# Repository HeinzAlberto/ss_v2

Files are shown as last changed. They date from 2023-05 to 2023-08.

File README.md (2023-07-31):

# ss_v2
Soldering Station v2 Projekt

Das Soldering Station v2 Projekt basiert auf dem SolderingStation Projekt: https://github.com/ConnyCola/SolderingStation.
Da dieses Projekt nun schon einige Jahre alt ist und mir ein paar kleine Tweeks wie USB-C input oder User-Buttons fehlen, ist dies somit die inoffizielle Fortsetzung.
Der Code basiert maßgebend auf dem des Originalprojekts. 
Hinzugefügt wurde:
- User-Buttons Funktionen (speichern, abrufen und löschen von selbst festgelegten Temperaturwerten)
- Automatisches Standby, wenn PWM über gewisse Zeit einen Wert nicht überschreitet
- Menü, um obriges einzustellen

Die Schaltung basiert ebenfalls auf dem Originalprojekt, wobei hier einige Änderungen vorgenommen wurden:
- Der uC (Atmega328p) wird direkt integriert.
- Es werden drei programmierbare Nutzer-Buttons hinzufügt, z.B. für voreingestellte Temperaturen oder Standby.
- Über einen Pin kann mit einem Federkontakt der Lötkolben automatisch in den Standy gesetzt werden, wenn er in die Halterung gelegt wird.
- Es gibt nun eine AVR-ISP-Schnittstelle zur Programmierung.
- Der OpAmp wurde durch ein günstigeres Modell ersetzt.
- Es gibt neben dem bisherigen Rundstecker auch einen USB-C Anschluss, der Power Delivery (USB-PD) unterstützt.
- Ein Kippschalter wird eingesetzt, um zwischen Rundstecker und USB-C zu schalten um somit reverse-current zu verhindern.

ToDo:
Der gesamte Programmierteil sowie ein Prüfen der Schaltung.

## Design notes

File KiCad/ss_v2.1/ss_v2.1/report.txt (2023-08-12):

Hinweis: Verarbeite Symbol "Q1:Package_TO_SOT_SMD:SOT-23".
Hinweis: Verarbeite Symbol "R21:Resistor_SMD:R_1206_3216Metric_Pad1.30x1.75mm_HandSolder".
Hinweis: Verarbeite Symbol "R3:Resistor_SMD:R_1206_3216Metric_Pad1.30x1.75mm_HandSolder".
Hinweis: Verarbeite Symbol "R2:Resistor_SMD:R_1206_3216Metric_Pad1.30x1.75mm_HandSolder".
Hinweis: Verarbeite Symbol "R22:Resistor_SMD:R_1206_3216Metric_Pad1.30x1.75mm_HandSolder".
Hinweis: Verarbeite Symbol "R1:Resistor_SMD:R_1206_3216Metric_Pad1.30x1.75mm_HandSolder".
Hinweis: Verarbeite Symbol "Q3:Package_TO_SOT_SMD:SOT-23".
Hinweis: Verarbeite Symbol "R23:Resistor_SMD:R_1206_3216Metric_Pad1.30x1.75mm_HandSolder".
Hinweis: Verarbeite Symbol "Q2:SO-8_IRF741_INF".
Hinweis: Verarbeite Symbol "R4:Resistor_SMD:R_1206_3216Metric_Pad1.30x1.75mm_HandSolder".
Hinweis: Verarbeite Symbol "R24:Resistor_SMD:R_1206_3216Metric_Pad1.30x1.75mm_HandSolder".
Hinweis: Verarbeite Symbol "L1:IND_NLCV32T_TDK".
Hinweis: Verarbeite Symbol "J8:CONN12_B-7004_GSW".
Hinweis: Verarbeite Symbol "J7:PJ-313D-B-SMT_XKB".
Hinweis: Verarbeite Symbol "J6:Connector_IDC:IDC-Header_2x03_P2.54mm_Vertical".
Hinweis: Verarbeite Symbol "R26:Resistor_SMD:R_1206_3216Metric_Pad1.30x1.75mm_HandSolder".
Hinweis: Verarbeite Symbol "J5:Connector:FanPinHeader_1x04_P2.54mm_Vertical".
Hinweis: Verarbeite Symbol "R18:Resistor_SMD:R_1206_3216Metric_Pad1.30x1.75mm_HandSolder".
Hinweis: Verarbeite Symbol "R15:Resistor_SMD:R_1206_3216Metric_Pad1.30x1.75mm_HandSolder".
Hinweis: Verarbeite Symbol "R14:Resistor_SMD:R_1206_3216Metric_Pad1.30x1.75mm_HandSolder".
Hinweis: Verarbeite Symbol "R16:Resistor_SMD:R_1206_3216Metric_Pad1.30x1.75mm_HandSolder".
Hinweis: Verarbeite Symbol "R13:Resistor_SMD:R_1206_3216Metric_Pad1.30x1.75mm_HandSolder".
Hinweis: Verarbeite Symbol "R12:Resistor_SMD:R_1206_3216Metric_Pad1.30x1.75mm_HandSolder".
Hinweis: Verarbeite Symbol "R17:Resistor_SMD:R_1206_3216Metric_Pad1.30x1.75mm_HandSolder".
Hinweis: Verarbeite Symbol "R11:Resistor_SMD:R_1206_3216Metric_Pad1.30x1.75mm_HandSolder".
Hinweis: Verarbeite Symbol "R10:Resistor_SMD:R_1206_3216Metric_Pad1.30x1.75mm_HandSolder".
Hinweis: Verarbeite Symbol "R25:Resistor_SMD:R_1206_3216Metric_Pad1.30x1.75mm_HandSolder".
Hinweis: Verarbeite Symbol "R9:Resistor_SMD:R_1206_3216Metric_Pad1.30x1.75mm_HandSolder".
Hinweis: Verarbeite Symbol "R8:Resistor_SMD:R_1206_3216Metric_Pad1.30x1.75mm_HandSolder".
Hinweis: Verarbeite Symbol "R19:Resistor_SMD:R_1206_3216Metric_Pad1.30x1.75mm_HandSolder".
Hinweis: Verarbeite Symbol "R7:Resistor_SMD:R_1206_3216Metric_Pad1.30x1.75mm_HandSolder".
Hinweis: Verarbeite Symbol "R6:Resistor_SMD:R_1206_3216Metric_Pad1.30x1.75mm_HandSolder".
Hinweis: Verarbeite Symbol "R20:Resistor_SMD:R_1206_3216Metric_Pad1.30x1.75mm_HandSolder".
Hinweis: Verarbeite Symbol "R5:Resistor_SMD:R_1206_3216Metric_Pad1.30x1.75mm_HandSolder".
Hinweis: Verarbeite Symbol "C6:Resistor_SMD:R_1206_3216Metric_Pad1.30x1.75mm_HandSolder".
Hinweis: Verarbeite Symbol "SW1:SW_TS-1093C-A15_YDI".
Hinweis: Verarbeite Symbol "C10:Resistor_SMD:R_1206_3216Metric_Pad1.30x1.75mm_HandSolder".
Hinweis: Verarbeite Symbol "C9:Resistor_SMD:R_1206_3216Metric_Pad1.30x1.75mm_HandSolder".
Hinweis: Verarbeite Symbol "SW3:SW_TS-1093C-A15_YDI".
Hinweis: Verarbeite Symbol "C8:Resistor_SMD:R_1206_3216Metric_Pad1.30x1.75mm_HandSolder".
Hinweis: Verarbeite Symbol "SW4:SW_TS-1093C-A15_YDI".
Hinweis: Verarbeite Symbol "C7:Resistor_SMD:R_1206_3216Metric_Pad1.30x1.75mm_HandSolder".
Hinweis: Verarbeite Symbol "U1:DQC0010A".
Hinweis: Verarbeite Symbol "SW2:SW_TS-1093C-A15_YDI".
Hinweis: Verarbeite Symbol "U3:Package_TO_SOT_SMD:SOT-23-5".
Hinweis: Verarbeite Symbol "C5:Resistor_SMD:R_1206_3216Metric_Pad1.30x1.75mm_HandSolder".
Hinweis: Verarbeite Symbol "C4:Resistor_SMD:R_1206_3216Metric_Pad1.30x1.75mm_HandSolder".
Hinweis: Verarbeite Symbol "U4:digikey-footprints:TQFP-32_7x7mm".
Hinweis: Verarbeite Symbol "C3:Resistor_SMD:R_1206_3216Metric_Pad1.30x1.75mm_HandSolder".
Hinweis: Verarbeite Symbol "Y1:Crystal:Crystal_HC49-U_Vertical".
Hinweis: Verarbeite Symbol "C2:Resistor_SMD:R_1206_3216Metric_Pad1.30x1.75mm_HandSolder".
Hinweis: Verarbeite Symbol "C1:Resistor_SMD:R_1206_3216Metric_Pad1.30x1.75mm_HandSolder".
Hinweis: Verarbeite Symbol "J4:Connector_IDC:IDC-Header_2x03_P2.54mm_Vertical".
Hinweis: Verarbeite Symbol "J1:Connector_Molex:Molex_SL_171971-0008_1x08_P2.54mm_Vertical".
Hinweis: Verarbeite Symbol "R28:Resistor_SMD:R_1206_3216Metric_Pad1.30x1.75mm_HandSolder".
Hinweis: Verarbeite Symbol "C11:Resistor_SMD:R_1206_3216Metric_Pad1.30x1.75mm_HandSolder".
Hinweis: Verarbeite Symbol "IC1:SOP100P600X180-11N".
Hinweis: Verarbeite Symbol "C13:Resistor_SMD:R_1206_3216Metric_Pad1.30x1.75mm_HandSolder".
Hinweis: Verarbeite Symbol "R29:Resistor_SMD:R_1206_3216Metric_Pad1.30x1.75mm_HandSolder".
Hinweis: Verarbeite Symbol "J2:DC00520A".
Hinweis: Verarbeite Symbol "R27:Resistor_SMD:R_1206_3216Metric_Pad1.30x1.75mm_HandSolder".
Hinweis: Verarbeite Symbol "C12:Resistor_SMD:R_1206_3216Metric_Pad1.30x1.75mm_HandSolder".
R25 hinzufügen (Footprint "Resistor_SMD:R_1206_3216Metric_Pad1.30x1.75mm_HandSolder").
R16 hinzufügen (Footprint "Resistor_SMD:R_1206_3216Metric_Pad1.30x1.75mm_HandSolder").
Y1 hinzufügen (Footprint "Crystal:Crystal_HC49-U_Vertical").
R27 hinzufügen (Footprint "Resistor_SMD:R_1206_3216Metric_Pad1.30x1.75mm_HandSolder").
R15 hinzufügen (Footprint "Resistor_SMD:R_1206_3216Metric_Pad1.30x1.75mm_HandSolder").
R18 hinzufügen (Footprint "Resistor_SMD:R_1206_3216Metric_Pad1.30x1.75mm_HandSolder").
U3 hinzufügen (Footprint "Package_TO_SOT_SMD:SOT-23-5").
R17 hinzufügen (Footprint "Resistor_SMD:R_1206_3216Metric_Pad1.30x1.75mm_HandSolder").
R24 hinzufügen (Footprint "Resistor_SMD:R_1206_3216Metric_Pad1.30x1.75mm_HandSolder").
R23 hinzufügen (Footprint "Resistor_SMD:R_1206_3216Metric_Pad1.30x1.75mm_HandSolder").
R28 hinzufügen (Footprint "Resistor_SMD:R_1206_3216Metric_Pad1.30x1.75mm_HandSolder").
R19 hinzufügen (Footprint "Resistor_SMD:R_1206_3216Metric_Pad1.30x1.75mm_HandSolder").
R22 hinzufügen (Footprint "Resistor_SMD:R_1206_3216Metric_Pad1.30x1.75mm_HandSolder").
R20 hinzufügen (Footprint "Resistor_SMD:R_1206_3216Metric_Pad1.30x1.75mm_HandSolder").
R26 hinzufügen (Footprint "Resistor_SMD:R_1206_3216Metric_Pad1.30x1.75mm_HandSolder").
R29 hinzufügen (Footprint "Resistor_SMD:R_1206_3216Metric_Pad1.30x1.75mm_HandSolder").
R21 hinzufügen (Footprint "Resistor_SMD:R_1206_3216Metric_Pad1.30x1.75mm_HandSolder").
C9 hinzufügen (Footprint "Resistor_SMD:R_1206_3216Metric_Pad1.30x1.75mm_HandSolder").
J6 hinzufügen (Footprint "Connector_IDC:IDC-Header_2x03_P2.54mm_Vertical").
J5 hinzufügen (Footprint "Connector:FanPinHeader_1x04_P2.54mm_Vertical").
R14 hinzufügen (Footprint "Resistor_SMD:R_1206_3216Metric_Pad1.30x1.75mm_HandSolder").
J1 hinzufügen (Footprint "Connector_Molex:Molex_SL_171971-0008_1x08_P2.54mm_Vertical").
C13 hinzufügen (Footprint "Resistor_SMD:R_1206_3216Metric_Pad1.30x1.75mm_HandSolder").
C12 hinzufügen (Footprint "Resistor_SMD:R_1206_3216Metric_Pad1.30x1.75mm_HandSolder").
C11 hinzufügen (Footprint "Resistor_SMD:R_1206_3216Metric_Pad1.30x1.75mm_HandSolder").
C10 hinzufügen (Footprint "Resistor_SMD:R_1206_3216Metric_Pad1.30x1.75mm_HandSolder").
J4 hinzufügen (Footprint "Connector_IDC:IDC-Header_2x03_P2.54mm_Vertical").
C8 hinzufügen (Footprint "Resistor_SMD:R_1206_3216Metric_Pad1.30x1.75mm_HandSolder").
C7 hinzufügen (Footprint "Resistor_SMD:R_1206_3216Metric_Pad1.30x1.75mm_HandSolder").
C6 hinzufügen (Footprint "Resistor_SMD:R_1206_3216Metric_Pad1.30x1.75mm_HandSolder").
C5 hinzufügen (Footprint "Resistor_SMD:R_1206_3216Metric_Pad1.30x1.75mm_HandSolder").
C4 hinzufügen (Footprint "Resistor_SMD:R_1206_3216Metric_Pad1.30x1.75mm_HandSolder").
C3 hinzufügen (Footprint "Resistor_SMD:R_1206_3216Metric_Pad1.30x1.75mm_HandSolder").
C2 hinzufügen (Footprint "Resistor_SMD:R_1206_3216Metric_Pad1.30x1.75mm_HandSolder").
C1 hinzufügen (Footprint "Resistor_SMD:R_1206_3216Metric_Pad1.30x1.75mm_HandSolder").
R5 hinzufügen (Footprint "Resistor_SMD:R_1206_3216Metric_Pad1.30x1.75mm_HandSolder").
R13 hinzufügen (Footprint "Resistor_SMD:R_1206_3216Metric_Pad1.30x1.75mm_HandSolder").
R12 hinzufügen (Footprint "Resistor_SMD:R_1206_3216Metric_Pad1.30x1.75mm_HandSolder").
R11 hinzufügen (Footprint "Resistor_SMD:R_1206_3216Metric_Pad1.30x1.75mm_HandSolder").
R10 hinzufügen (Footprint "Resistor_SMD:R_1206_3216Metric_Pad1.30x1.75mm_HandSolder").
R9 hinzufügen (Footprint "Resistor_SMD:R_1206_3216Metric_Pad1.30x1.75mm_HandSolder").
R8 hinzufügen (Footprint "Resistor_SMD:R_1206_3216Metric_Pad1.30x1.75mm_HandSolder").
R7 hinzufügen (Footprint "Resistor_SMD:R_1206_3216Metric_Pad1.30x1.75mm_HandSolder").
R6 hinzufügen (Footprint "Resistor_SMD:R_1206_3216Metric_Pad1.30x1.75mm_HandSolder").
R4 hinzufügen (Footprint "Resistor_SMD:R_1206_3216Metric_Pad1.30x1.75mm_HandSolder").
R2 hinzufügen (Footprint "Resistor_SMD:R_1206_3216Metric_Pad1.30x1.75mm_HandSolder").
R3 hinzufügen (Footprint "Resistor_SMD:R_1206_3216Metric_Pad1.30x1.75mm_HandSolder").
R1 hinzufügen (Footprint "Resistor_SMD:R_1206_3216Metric_Pad1.30x1.75mm_HandSolder").
Q1 hinzufügen (Footprint "Package_TO_SOT_SMD:SOT-23").
Q3 hinzufügen (Footprint "Package_TO_SOT_SMD:SOT-23").
Fehler: Kann J7 nicht hinzufügen (Footprint "PJ-313D-B-SMT_XKB" nicht gefunden).
Fehler: Kann L1 nicht hinzufügen (Footprint "IND_NLCV32T_TDK" nicht gefunden).
Fehler: Kann U4 nicht hinzufügen (Footprint "digikey-footprints:TQFP-32_7x7mm" nicht gefunden).
Fehler: Kann Q2 nicht hinzufügen (Footprint "SO-8_IRF741_INF" nicht gefunden).
Fehler: Kann J2 nicht hinzufügen (Footprint "DC00520A" nicht gefunden).
Fehler: Kann U1 nicht hinzufügen (Footprint "DQC0010A" nicht gefunden).
Fehler: Kann SW4 nicht hinzufügen (Footprint "SW_TS-1093C-A15_YDI" nicht gefunden).
Fehler: Kann IC1 nicht hinzufügen (Footprint "SOP100P600X180-11N" nicht gefunden).
Fehler: Kann SW3 nicht hinzufügen (Footprint "SW_TS-1093C-A15_YDI" nicht gefunden).
Fehler: Kann SW2 nicht hinzufügen (Footprint "SW_TS-1093C-A15_YDI" nicht gefunden).
Fehler: Kann J8 nicht hinzufügen (Footprint "CONN12_B-7004_GSW" nicht gefunden).
Fehler: Kann SW1 nicht hinzufügen (Footprint "SW_TS-1093C-A15_YDI" nicht gefunden).

Hinweis: Warnungen insgesamt: 0, Fehler insgesamt: 12.

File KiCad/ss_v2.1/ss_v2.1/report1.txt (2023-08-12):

Hinweis: Verarbeite Symbol "Q3:Package_TO_SOT_SMD:SOT-23".
Hinweis: Verarbeite Symbol "R5:Resistor_SMD:R_1206_3216Metric_Pad1.30x1.75mm_HandSolder".
Hinweis: Verarbeite Symbol "R24:Resistor_SMD:R_1206_3216Metric_Pad1.30x1.75mm_HandSolder".
Hinweis: Verarbeite Symbol "R4:Resistor_SMD:R_1206_3216Metric_Pad1.30x1.75mm_HandSolder".
Hinweis: Verarbeite Symbol "R3:Resistor_SMD:R_1206_3216Metric_Pad1.30x1.75mm_HandSolder".
Hinweis: Verarbeite Symbol "R25:Resistor_SMD:R_1206_3216Metric_Pad1.30x1.75mm_HandSolder".
Hinweis: Verarbeite Symbol "R2:Resistor_SMD:R_1206_3216Metric_Pad1.30x1.75mm_HandSolder".
Hinweis: Verarbeite Symbol "R1:Resistor_SMD:R_1206_3216Metric_Pad1.30x1.75mm_HandSolder".
Hinweis: Verarbeite Symbol "R26:Resistor_SMD:R_1206_3216Metric_Pad1.30x1.75mm_HandSolder".
Hinweis: Verarbeite Symbol "R6:Resistor_SMD:R_1206_3216Metric_Pad1.30x1.75mm_HandSolder".
Hinweis: Verarbeite Symbol "Q2:SO-8_IRF741_INF".
Hinweis: Verarbeite Symbol "R27:Resistor_SMD:R_1206_3216Metric_Pad1.30x1.75mm_HandSolder".
Hinweis: Verarbeite Symbol "Q1:Package_TO_SOT_SMD:SOT-23".
Hinweis: Verarbeite Symbol "L1:IND_NLCV32T_TDK".
Hinweis: Verarbeite Symbol "J8:CONN12_B-7004_GSW".
Hinweis: Verarbeite Symbol "J7:PJ-313D-B-SMT_XKB".
Hinweis: Verarbeite Symbol "R29:Resistor_SMD:R_1206_3216Metric_Pad1.30x1.75mm_HandSolder".
Hinweis: Verarbeite Symbol "J6:Connector_IDC:IDC-Header_2x03_P2.54mm_Vertical".
Hinweis: Verarbeite Symbol "R12:Resistor_SMD:R_1206_3216Metric_Pad1.30x1.75mm_HandSolder".
Hinweis: Verarbeite Symbol "R17:Resistor_SMD:R_1206_3216Metric_Pad1.30x1.75mm_HandSolder".
Hinweis: Verarbeite Symbol "R18:Resistor_SMD:R_1206_3216Metric_Pad1.30x1.75mm_HandSolder".
Hinweis: Verarbeite Symbol "R16:Resistor_SMD:R_1206_3216Metric_Pad1.30x1.75mm_HandSolder".
Hinweis: Verarbeite Symbol "R15:Resistor_SMD:R_1206_3216Metric_Pad1.30x1.75mm_HandSolder".
Hinweis: Verarbeite Symbol "R19:Resistor_SMD:R_1206_3216Metric_Pad1.30x1.75mm_HandSolder".
Hinweis: Verarbeite Symbol "R14:Resistor_SMD:R_1206_3216Metric_Pad1.30x1.75mm_HandSolder".
Hinweis: Verarbeite Symbol "R13:Resistor_SMD:R_1206_3216Metric_Pad1.30x1.75mm_HandSolder".
Hinweis: Verarbeite Symbol "R20:Resistor_SMD:R_1206_3216Metric_Pad1.30x1.75mm_HandSolder".
Hinweis: Verarbeite Symbol "R28:Resistor_SMD:R_1206_3216Metric_Pad1.30x1.75mm_HandSolder".
Hinweis: Verarbeite Symbol "R11:Resistor_SMD:R_1206_3216Metric_Pad1.30x1.75mm_HandSolder".
Hinweis: Verarbeite Symbol "R21:Resistor_SMD:R_1206_3216Metric_Pad1.30x1.75mm_HandSolder".
Hinweis: Verarbeite Symbol "R10:Resistor_SMD:R_1206_3216Metric_Pad1.30x1.75mm_HandSolder".
Hinweis: Verarbeite Symbol "R9:Resistor_SMD:R_1206_3216Metric_Pad1.30x1.75mm_HandSolder".
Hinweis: Verarbeite Symbol "R22:Resistor_SMD:R_1206_3216Metric_Pad1.30x1.75mm_HandSolder".
Hinweis: Verarbeite Symbol "R8:Resistor_SMD:R_1206_3216Metric_Pad1.30x1.75mm_HandSolder".
Hinweis: Verarbeite Symbol "R7:Resistor_SMD:R_1206_3216Metric_Pad1.30x1.75mm_HandSolder".
Hinweis: Verarbeite Symbol "R23:Resistor_SMD:R_1206_3216Metric_Pad1.30x1.75mm_HandSolder".
Hinweis: Verarbeite Symbol "C7:Resistor_SMD:R_1206_3216Metric_Pad1.30x1.75mm_HandSolder".
Hinweis: Verarbeite Symbol "C12:Resistor_SMD:R_1206_3216Metric_Pad1.30x1.75mm_HandSolder".
Hinweis: Verarbeite Symbol "SW4:SW_TS-1093C-A15_YDI".
Hinweis: Verarbeite Symbol "C11:Resistor_SMD:R_1206_3216Metric_Pad1.30x1.75mm_HandSolder".
Hinweis: Verarbeite Symbol "C10:Resistor_SMD:R_1206_3216Metric_Pad1.30x1.75mm_HandSolder".
Hinweis: Verarbeite Symbol "U1:DQC0010A".
Hinweis: Verarbeite Symbol "C9:Resistor_SMD:R_1206_3216Metric_Pad1.30x1.75mm_HandSolder".
Hinweis: Verarbeite Symbol "C8:Resistor_SMD:R_1206_3216Metric_Pad1.30x1.75mm_HandSolder".
Hinweis: Verarbeite Symbol "U3:Package_TO_SOT_SMD:SOT-23-5".
Hinweis: Verarbeite Symbol "J5:Connector:FanPinHeader_1x04_P2.54mm_Vertical".
Hinweis: Verarbeite Symbol "C6:Resistor_SMD:R_1206_3216Metric_Pad1.30x1.75mm_HandSolder".
Hinweis: Verarbeite Symbol "U4:TQFP-32_7x7mm:QFP80P900X900X120-32N".
Hinweis: Verarbeite Symbol "C5:Resistor_SMD:R_1206_3216Metric_Pad1.30x1.75mm_HandSolder".
Hinweis: Verarbeite Symbol "C4:Resistor_SMD:R_1206_3216Metric_Pad1.30x1.75mm_HandSolder".
Hinweis: Verarbeite Symbol "Y1:Crystal:Crystal_HC49-U_Vertical".
Hinweis: Verarbeite Symbol "C3:Resistor_SMD:R_1206_3216Metric_Pad1.30x1.75mm_HandSolder".
Hinweis: Verarbeite Symbol "C2:Resistor_SMD:R_1206_3216Metric_Pad1.30x1.75mm_HandSolder".
Hinweis: Verarbeite Symbol "C1:Resistor_SMD:R_1206_3216Metric_Pad1.30x1.75mm_HandSolder".
Hinweis: Verarbeite Symbol "C13:Resistor_SMD:R_1206_3216Metric_Pad1.30x1.75mm_HandSolder".
Hinweis: Verarbeite Symbol "SW1:SW_TS-1093C-A15_YDI".
Hinweis: Verarbeite Symbol "J2:DC00520A".
Hinweis: Verarbeite Symbol "SW3:SW_TS-1093C-A15_YDI".
Hinweis: Verarbeite Symbol "IC1:SOP100P600X180-11N".
Hinweis: Verarbeite Symbol "SW2:SW_TS-1093C-A15_YDI".
Hinweis: Verarbeite Symbol "J4:Connector_IDC:IDC-Header_2x03_P2.54mm_Vertical".
Hinweis: Verarbeite Symbol "J1:Connector_Molex:Molex_SL_171971-0008_1x08_P2.54mm_Vertical".
R27 hinzufügen (Footprint "Resistor_SMD:R_1206_3216Metric_Pad1.30x1.75mm_HandSolder").
R29 hinzufügen (Footprint "Resistor_SMD:R_1206_3216Metric_Pad1.30x1.75mm_HandSolder").
SW1 hinzufügen (Footprint "SW_TS-1093C-A15_YDI").
U4 hinzufügen (Footprint "TQFP-32_7x7mm:QFP80P900X900X120-32N").
R19 hinzufügen (Footprint "Resistor_SMD:R_1206_3216Metric_Pad1.30x1.75mm_HandSolder").
C1 hinzufügen (Footprint "Resistor_SMD:R_1206_3216Metric_Pad1.30x1.75mm_HandSolder").
R28 hinzufügen (Footprint "Resistor_SMD:R_1206_3216Metric_Pad1.30x1.75mm_HandSolder").
R18 hinzufügen (Footprint "Resistor_SMD:R_1206_3216Metric_Pad1.30x1.75mm_HandSolder").
Y1 hinzufügen (Footprint "Crystal:Crystal_HC49-U_Vertical").
SW3 hinzufügen (Footprint "SW_TS-1093C-A15_YDI").
R20 hinzufügen (Footprint "Resistor_SMD:R_1206_3216Metric_Pad1.30x1.75mm_HandSolder").
U3 hinzufügen (Footprint "Package_TO_SOT_SMD:SOT-23-5").
R21 hinzufügen (Footprint "Resistor_SMD:R_1206_3216Metric_Pad1.30x1.75mm_HandSolder").
R26 hinzufügen (Footprint "Resistor_SMD:R_1206_3216Metric_Pad1.30x1.75mm_HandSolder").
U1 hinzufügen (Footprint "DQC0010A").
R22 hinzufügen (Footprint "Resistor_SMD:R_1206_3216Metric_Pad1.30x1.75mm_HandSolder").
SW2 hinzufügen (Footprint "SW_TS-1093C-A15_YDI").
R23 hinzufügen (Footprint "Resistor_SMD:R_1206_3216Metric_Pad1.30x1.75mm_HandSolder").
SW4 hinzufügen (Footprint "SW_TS-1093C-A15_YDI").
R25 hinzufügen (Footprint "Resistor_SMD:R_1206_3216Metric_Pad1.30x1.75mm_HandSolder").
R24 hinzufügen (Footprint "Resistor_SMD:R_1206_3216Metric_Pad1.30x1.75mm_HandSolder").
C11 hinzufügen (Footprint "Resistor_SMD:R_1206_3216Metric_Pad1.30x1.75mm_HandSolder").
J8 hinzufügen (Footprint "CONN12_B-7004_GSW").
J7 hinzufügen (Footprint "PJ-313D-B-SMT_XKB").
J6 hinzufügen (Footprint "Connector_IDC:IDC-Header_2x03_P2.54mm_Vertical").
J5 hinzufügen (Footprint "Connector:FanPinHeader_1x04_P2.54mm_Vertical").
J4 hinzufügen (Footprint "Connector_IDC:IDC-Header_2x03_P2.54mm_Vertical").
J2 hinzufügen (Footprint "DC00520A").
J1 hinzufügen (Footprint "Connector_Molex:Molex_SL_171971-0008_1x08_P2.54mm_Vertical").
IC1 hinzufügen (Footprint "SOP100P600X180-11N").
C13 hinzufügen (Footprint "Resistor_SMD:R_1206_3216Metric_Pad1.30x1.75mm_HandSolder").
C12 hinzufügen (Footprint "Resistor_SMD:R_1206_3216Metric_Pad1.30x1.75mm_HandSolder").
R16 hinzufügen (Footprint "Resistor_SMD:R_1206_3216Metric_Pad1.30x1.75mm_HandSolder").
C10 hinzufügen (Footprint "Resistor_SMD:R_1206_3216Metric_Pad1.30x1.75mm_HandSolder").
C9 hinzufügen (Footprint "Resistor_SMD:R_1206_3216Metric_Pad1.30x1.75mm_HandSolder").
C8 hinzufügen (Footprint "Resistor_SMD:R_1206_3216Metric_Pad1.30x1.75mm_HandSolder").
C7 hinzufügen (Footprint "Resistor_SMD:R_1206_3216Metric_Pad1.30x1.75mm_HandSolder").
C6 hinzufügen (Footprint "Resistor_SMD:R_1206_3216Metric_Pad1.30x1.75mm_HandSolder").
C5 hinzufügen (Footprint "Resistor_SMD:R_1206_3216Metric_Pad1.30x1.75mm_HandSolder").
C4 hinzufügen (Footprint "Resistor_SMD:R_1206_3216Metric_Pad1.30x1.75mm_HandSolder").
C3 hinzufügen (Footprint "Resistor_SMD:R_1206_3216Metric_Pad1.30x1.75mm_HandSolder").
C2 hinzufügen (Footprint "Resistor_SMD:R_1206_3216Metric_Pad1.30x1.75mm_HandSolder").
Q1 hinzufügen (Footprint "Package_TO_SOT_SMD:SOT-23").
R17 hinzufügen (Footprint "Resistor_SMD:R_1206_3216Metric_Pad1.30x1.75mm_HandSolder").
R15 hinzufügen (Footprint "Resistor_SMD:R_1206_3216Metric_Pad1.30x1.75mm_HandSolder").
R14 hinzufügen (Footprint "Resistor_SMD:R_1206_3216Metric_Pad1.30x1.75mm_HandSolder").
R13 hinzufügen (Footprint "Resistor_SMD:R_1206_3216Metric_Pad1.30x1.75mm_HandSolder").
R12 hinzufügen (Footprint "Resistor_SMD:R_1206_3216Metric_Pad1.30x1.75mm_HandSolder").
R11 hinzufügen (Footprint "Resistor_SMD:R_1206_3216Metric_Pad1.30x1.75mm_HandSolder").
R10 hinzufügen (Footprint "Resistor_SMD:R_1206_3216Metric_Pad1.30x1.75mm_HandSolder").
R9 hinzufügen (Footprint "Resistor_SMD:R_1206_3216Metric_Pad1.30x1.75mm_HandSolder").
R8 hinzufügen (Footprint "Resistor_SMD:R_1206_3216Metric_Pad1.30x1.75mm_HandSolder").
R7 hinzufügen (Footprint "Resistor_SMD:R_1206_3216Metric_Pad1.30x1.75mm_HandSolder").
R6 hinzufügen (Footprint "Resistor_SMD:R_1206_3216Metric_Pad1.30x1.75mm_HandSolder").
R5 hinzufügen (Footprint "Resistor_SMD:R_1206_3216Metric_Pad1.30x1.75mm_HandSolder").
R4 hinzufügen (Footprint "Resistor_SMD:R_1206_3216Metric_Pad1.30x1.75mm_HandSolder").
R3 hinzufügen (Footprint "Resistor_SMD:R_1206_3216Metric_Pad1.30x1.75mm_HandSolder").
R2 hinzufügen (Footprint "Resistor_SMD:R_1206_3216Metric_Pad1.30x1.75mm_HandSolder").
R1 hinzufügen (Footprint "Resistor_SMD:R_1206_3216Metric_Pad1.30x1.75mm_HandSolder").
Q3 hinzufügen (Footprint "Package_TO_SOT_SMD:SOT-23").
Q2 hinzufügen (Footprint "SO-8_IRF741_INF").
L1 hinzufügen (Footprint "IND_NLCV32T_TDK").
Warnung: Via mit unbekannten Netz (sda) verbunden.
Warnung: Via mit unbekannten Netz (sda) verbunden.
Warnung: Via mit unbekannten Netz (unconnected-(U1-PD0-Pad30)) verbunden.
Warnung: Via mit unbekannten Netz (unconnected-(U1-PD0-Pad30)) verbunden.
Warnung: Via mit unbekannten Netz (unconnected-(U1-PD1-Pad31)) verbunden.

Hinweis: Warnungen insgesamt: 5, Fehler insgesamt: 0.

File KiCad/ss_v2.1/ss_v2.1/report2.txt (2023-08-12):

Hinweis: Verarbeite Symbol "SW1:SW_TS-1093C-A15_YDI".
Hinweis: Verarbeite Symbol "J7:PJ-313D-B-SMT_XKB".
Hinweis: Verarbeite Symbol "R23:Resistor_SMD:R_1206_3216Metric_Pad1.30x1.75mm_HandSolder".
Hinweis: Verarbeite Symbol "R24:Resistor_SMD:R_1206_3216Metric_Pad1.30x1.75mm_HandSolder".
Hinweis: Verarbeite Symbol "J6:Connector_IDC:IDC-Header_2x03_P2.54mm_Vertical".
Hinweis: Verarbeite Symbol "R25:Resistor_SMD:R_1206_3216Metric_Pad1.30x1.75mm_HandSolder".
Hinweis: Verarbeite Symbol "J5:Connector:FanPinHeader_1x04_P2.54mm_Vertical".
Hinweis: Verarbeite Symbol "R26:Resistor_SMD:R_1206_3216Metric_Pad1.30x1.75mm_HandSolder".
Hinweis: Verarbeite Symbol "J4:Connector_IDC:IDC-Header_2x03_P2.54mm_Vertical".
Hinweis: Verarbeite Symbol "R27:Resistor_SMD:R_1206_3216Metric_Pad1.30x1.75mm_HandSolder".
Hinweis: Verarbeite Symbol "J2:DC00520A".
Hinweis: Verarbeite Symbol "R28:Resistor_SMD:R_1206_3216Metric_Pad1.30x1.75mm_HandSolder".
Hinweis: Verarbeite Symbol "R29:Resistor_SMD:R_1206_3216Metric_Pad1.30x1.75mm_HandSolder".
Hinweis: Verarbeite Symbol "J1:Connector_Molex:Molex_SL_171971-0008_1x08_P2.54mm_Vertical".
Hinweis: Verarbeite Symbol "R22:Resistor_SMD:R_1206_3216Metric_Pad1.30x1.75mm_HandSolder".
Hinweis: Verarbeite Symbol "SW2:SW_TS-1093C-A15_YDI".
Hinweis: Verarbeite Symbol "SW3:SW_TS-1093C-A15_YDI".
Hinweis: Verarbeite Symbol "IC1:SOP100P600X180-11N".
Hinweis: Verarbeite Symbol "SW4:SW_TS-1093C-A15_YDI".
Hinweis: Verarbeite Symbol "C13:Resistor_SMD:R_1206_3216Metric_Pad1.30x1.75mm_HandSolder".
Hinweis: Verarbeite Symbol "U1:DQC0010A".
Hinweis: Verarbeite Symbol "C12:Resistor_SMD:R_1206_3216Metric_Pad1.30x1.75mm_HandSolder".
Hinweis: Verarbeite Symbol "C11:Resistor_SMD:R_1206_3216Metric_Pad1.30x1.75mm_HandSolder".
Hinweis: Verarbeite Symbol "C10:Resistor_SMD:R_1206_3216Metric_Pad1.30x1.75mm_HandSolder".
Hinweis: Verarbeite Symbol "U3:Package_TO_SOT_SMD:SOT-23-5".
Hinweis: Verarbeite Symbol "C9:Resistor_SMD:R_1206_3216Metric_Pad1.30x1.75mm_HandSolder".
Hinweis: Verarbeite Symbol "U4:TQFP-32_7x7mm:QFP80P900X900X120-32N".
Hinweis: Verarbeite Symbol "C8:Resistor_SMD:R_1206_3216Metric_Pad1.30x1.75mm_HandSolder".
Hinweis: Verarbeite Symbol "R14:Resistor_SMD:R_1206_3216Metric_Pad1.30x1.75mm_HandSolder".
Hinweis: Verarbeite Symbol "R8:Resistor_SMD:R_1206_3216Metric_Pad1.30x1.75mm_HandSolder".
Hinweis: Verarbeite Symbol "R7:Resistor_SMD:R_1206_3216Metric_Pad1.30x1.75mm_HandSolder".
Hinweis: Verarbeite Symbol "R9:Resistor_SMD:R_1206_3216Metric_Pad1.30x1.75mm_HandSolder".
Hinweis: Verarbeite Symbol "R6:Resistor_SMD:R_1206_3216Metric_Pad1.30x1.75mm_HandSolder".
Hinweis: Verarbeite Symbol "R10:Resistor_SMD:R_1206_3216Metric_Pad1.30x1.75mm_HandSolder".
Hinweis: Verarbeite Symbol "R5:Resistor_SMD:R_1206_3216Metric_Pad1.30x1.75mm_HandSolder".
Hinweis: Verarbeite Symbol "R11:Resistor_SMD:R_1206_3216Metric_Pad1.30x1.75mm_HandSolder".
Hinweis: Verarbeite Symbol "R4:Resistor_SMD:R_1206_3216Metric_Pad1.30x1.75mm_HandSolder".
Hinweis: Verarbeite Symbol "R12:Resistor_SMD:R_1206_3216Metric_Pad1.30x1.75mm_HandSolder".
Hinweis: Verarbeite Symbol "R3:Resistor_SMD:R_1206_3216Metric_Pad1.30x1.75mm_HandSolder".
Hinweis: Verarbeite Symbol "R13:Resistor_SMD:R_1206_3216Metric_Pad1.30x1.75mm_HandSolder".
Hinweis: Verarbeite Symbol "R2:Resistor_SMD:R_1206_3216Metric_Pad1.30x1.75mm_HandSolder".
Hinweis: Verarbeite Symbol "R1:Resistor_SMD:R_1206_3216Metric_Pad1.30x1.75mm_HandSolder".
Hinweis: Verarbeite Symbol "C1:Resistor_SMD:R_1206_3216Metric_Pad1.30x1.75mm_HandSolder".
Hinweis: Verarbeite Symbol "Q3:Package_TO_SOT_SMD:SOT-23".
Hinweis: Verarbeite Symbol "R15:Resistor_SMD:R_1206_3216Metric_Pad1.30x1.75mm_HandSolder".
Hinweis: Verarbeite Symbol "R16:Resistor_SMD:R_1206_3216Metric_Pad1.30x1.75mm_HandSolder".
Hinweis: Verarbeite Symbol "Q2:SO-8_IRF741_INF".
Hinweis: Verarbeite Symbol "R17:Resistor_SMD:R_1206_3216Metric_Pad1.30x1.75mm_HandSolder".
Hinweis: Verarbeite Symbol "Q1:Package_TO_SOT_SMD:SOT-23".
Hinweis: Verarbeite Symbol "R18:Resistor_SMD:R_1206_3216Metric_Pad1.30x1.75mm_HandSolder".
Hinweis: Verarbeite Symbol "L1:IND_NLCV32T_TDK".
Hinweis: Verarbeite Symbol "R19:Resistor_SMD:R_1206_3216Metric_Pad1.30x1.75mm_HandSolder".
Hinweis: Verarbeite Symbol "R20:Resistor_SMD:R_1206_3216Metric_Pad1.30x1.75mm_HandSolder".
Hinweis: Verarbeite Symbol "R21:Resistor_SMD:R_1206_3216Metric_Pad1.30x1.75mm_HandSolder".
Hinweis: Verarbeite Symbol "J8:CONN12_B-7004_GSW".
Hinweis: Verarbeite Symbol "C7:Resistor_SMD:R_1206_3216Metric_Pad1.30x1.75mm_HandSolder".
Hinweis: Verarbeite Symbol "Y1:Crystal:Crystal_HC49-U_Vertical".
Hinweis: Verarbeite Symbol "C3:Resistor_SMD:R_1206_3216Metric_Pad1.30x1.75mm_HandSolder".
Hinweis: Verarbeite Symbol "C6:Resistor_SMD:R_1206_3216Metric_Pad1.30x1.75mm_HandSolder".
Hinweis: Verarbeite Symbol "C5:Resistor_SMD:R_1206_3216Metric_Pad1.30x1.75mm_HandSolder".
Hinweis: Verarbeite Symbol "C2:Resistor_SMD:R_1206_3216Metric_Pad1.30x1.75mm_HandSolder".
Hinweis: Verarbeite Symbol "C4:Resistor_SMD:R_1206_3216Metric_Pad1.30x1.75mm_HandSolder".
Netz unconnected-(U4-PC4-Pad27) hinzufügen.
Symbolverknüpfung R17 von  nach /7ae68144-be01-4aae-85ba-bd4ee85be67d aktualisiert.
R17 Eigenschaften aktualisiert.
R17 Pin 1 nach Net-(U1-FB) verbunden.
R17 Pin 2 nach GND verbunden.
U4 Pin 27 nach unconnected-(U4-PC4-Pad27) verbunden.
R18 hinzugefügt (Footprint "Resistor_SMD:R_1206_3216Metric_Pad1.30x1.75mm_HandSolder").
Referenzbezeichner REF** in R18 geändert.
Wert R18 von R_1206_3216Metric_Pad1.30x1.75mm_HandSolder in 10k geändert.
Wert R17 von R_1206_3216Metric_Pad1.30x1.75mm_HandSolder in 51k geändert.
Symbolverknüpfung R18 von  nach /8d95fd4f-8f14-4b74-95c8-f838c9daa1ba aktualisiert.
R18 Eigenschaften aktualisiert.
R18 Pin 1 nach +5V verbunden.
R18 Pin 2 nach pd-cfg verbunden.
R16 Eigenschaften aktualisiert.
R15 Pin 1 nach standby verbunden.
R15 Pin 2 nach GND verbunden.
Netz unconnected-(U4-PD0-Pad30) hinzufügen.
R16 hinzugefügt (Footprint "Resistor_SMD:R_1206_3216Metric_Pad1.30x1.75mm_HandSolder").
Referenzbezeichner REF** in R16 geändert.
Wert R16 von R_1206_3216Metric_Pad1.30x1.75mm_HandSolder in 270k geändert.
Symbolverknüpfung R16 von  nach /17c73df0-2805-40a3-89cc-e42629123f8f aktualisiert.
U4 Pin 29 nach reset verbunden.
Netz unconnected-(U4-PC5-Pad28) hinzufügen.
R16 Pin 1 nach +5V verbunden.
Netz Net-(U1-FB) hinzufügen.
R16 Pin 2 nach Net-(U1-FB) verbunden.
U4 Pin 28 nach unconnected-(U4-PC5-Pad28) verbunden.
R17 hinzugefügt (Footprint "Resistor_SMD:R_1206_3216Metric_Pad1.30x1.75mm_HandSolder").
Referenzbezeichner REF** in R17 geändert.
R19 hinzugefügt (Footprint "Resistor_SMD:R_1206_3216Metric_Pad1.30x1.75mm_HandSolder").
R22 hinzugefügt (Footprint "Resistor_SMD:R_1206_3216Metric_Pad1.30x1.75mm_HandSolder").
Referenzbezeichner REF** in R21 geändert.
Wert R21 von R_1206_3216Metric_Pad1.30x1.75mm_HandSolder in 10k geändert.
Symbolverknüpfung R21 von  nach /957c6a6f-07fb-4a42-8986-360b80f40343 aktualisiert.
U4 Pin 24 nach u3 verbunden.
R21 Eigenschaften aktualisiert.
R21 Pin 1 nach pd-cfg verbunden.
R21 Pin 2 nach GND verbunden.
U4 Pin 23 nach sb verbunden.
R21 hinzugefügt (Footprint "Resistor_SMD:R_1206_3216Metric_Pad1.30x1.75mm_HandSolder").
Referenzbezeichner REF** in R22 geändert.
Wert R22 von R_1206_3216Metric_Pad1.30x1.75mm_HandSolder in 1M geändert.
Symbolverknüpfung R22 von  nach /3d9306ed-9826-4033-8271-e34309bce412 aktualisiert.
R22 Eigenschaften aktualisiert.
R22 Pin 1 nach +5V verbunden.
R22 Pin 2 nach sens verbunden.
U4 Pin 22 nach unconnected-(U4-ADC7-Pad22) verbunden.
U4 Pin 26 nach u1 verbunden.
U4 Pin 25 nach u2 verbunden.
R20 Pin 2 nach Net-(Q3-G) verbunden.
R20 Pin 1 nach GND verbunden.
R20 Eigenschaften aktualisiert.
Symbolverknüpfung R20 von  nach /0bb319f2-a169-4299-9d58-c4af522e57fe aktualisiert.
Wert R20 von R_1206_3216Metric_Pad1.30x1.75mm_HandSolder in 10k geändert.
Referenzbezeichner REF** in R20 geändert.
R20 hinzugefügt (Footprint "Resistor_SMD:R_1206_3216Metric_Pad1.30x1.75mm_HandSolder").
R19 Pin 2 nach Net-(Q3-G) verbunden.
R19 Pin 1 nach bl_ctrl verbunden.
R19 Eigenschaften aktualisiert.
Symbolverknüpfung R19 von  nach /1d4ab079-4b76-49c4-b1b1-0470c781e87f aktualisiert.
Wert R19 von R_1206_3216Metric_Pad1.30x1.75mm_HandSolder in 1k geändert.
Referenzbezeichner REF** in R19 geändert.
Wert R15 von R_1206_3216Metric_Pad1.30x1.75mm_HandSolder in 10k geändert.
R10 Pin 1 nach +5V verbunden.
R9 Pin 2 nach Net-(J1-Pin_7) verbunden.
Symbolverknüpfung Y1 von  nach /c5d5f07e-399f-49ac-a6c4-e5f62a8c00e7 aktualisiert.
R10 hinzugefügt (Footprint "Resistor_SMD:R_1206_3216Metric_Pad1.30x1.75mm_HandSolder").
Referenzbezeichner REF** in R10 geändert.
Wert R10 von R_1206_3216Metric_Pad1.30x1.75mm_HandSolder in 10k geändert.
Wert Y1 von Crystal_HC49-U_Vertical in Crystal geändert.
Symbolverknüpfung R10 von  nach /7e6a5c3b-a194-4017-a8cf-e9c0ce40f2ec aktualisiert.
R10 Eigenschaften aktualisiert.
R9 Pin 1 nach cs verbunden.
R10 Pin 2 nach u3 verbunden.
Referenzbezeichner REF** in Y1 geändert.
R11 hinzugefügt (Footprint "Resistor_SMD:R_1206_3216Metric_Pad1.30x1.75mm_HandSolder").
Referenzbezeichner REF** in R11 geändert.
Wert R11 von R_1206_3216Metric_Pad1.30x1.75mm_HandSolder in 1k geändert.
Symbolverknüpfung R11 von  nach /652c5314-7235-4599-86e4-3f8b12484e7c aktualisiert.
R11 Eigenschaften aktualisiert.
R8 Pin 2 nach Net-(J1-Pin_6) verbunden.
C1 hinzugefügt (Footprint "Resistor_SMD:R_1206_3216Metric_Pad1.30x1.75mm_HandSolder").
R8 hinzugefügt (Footprint "Resistor_SMD:R_1206_3216Metric_Pad1.30x1.75mm_HandSolder").
Referenzbezeichner REF** in R8 geändert.
Wert R8 von R_1206_3216Metric_Pad1.30x1.75mm_HandSolder in 1k geändert.
Symbolverknüpfung R8 von  nach /83b5e7e5-5992-46ef-ae7b-34ec74c49cf4 aktualisiert.
R8 Eigenschaften aktualisiert.
Y1 Pin 2 nach Net-(U4-PB7) verbunden.
R8 Pin 1 nach dc verbunden.
R11 Pin 1 nach Net-(Q2-G) verbunden.
Y1 Pin 1 nach Net-(U4-PB6) verbunden.
R9 hinzugefügt (Footprint "Resistor_SMD:R_1206_3216Metric_Pad1.30x1.75mm_HandSolder").
Referenzbezeichner REF** in R9 geändert.
Wert R9 von R_1206_3216Metric_Pad1.30x1.75mm_HandSolder in 1k geändert.
Symbolverknüpfung R9 von  nach /27070cbe-f660-4307-96c0-23c06a641801 aktualisiert.
Y1 Eigenschaften aktualisiert.
R9 Eigenschaften aktualisiert.
R14 Eigenschaften aktualisiert.
R13 Pin 1 nach poti verbunden.
R13 Pin 2 nach GND verbunden.
U4 Pin 31 nach unconnected-(U4-PD1-Pad31) verbunden.
Netz unconnected-(U4-PD1-Pad31) hinzufügen.
R14 hinzugefügt (Footprint "Resistor_SMD:R_1206_3216Metric_Pad1.30x1.75mm_HandSolder").
Referenzbezeichner REF** in R14 geändert.
Wert R14 von R_1206_3216Metric_Pad1.30x1.75mm_HandSolder in 10k geändert.
Symbolverknüpfung R14 von  nach /372a38a1-05da-45d5-949d-cebb02088814 aktualisiert.
R13 Eigenschaften aktualisiert.
R14 Pin 1 nach +5V verbunden.
R14 Pin 2 nach standby verbunden.
U4 Pin 30 nach unconnected-(U4-PD0-Pad30) verbunden.
R15 hinzugefügt (Footprint "Resistor_SMD:R_1206_3216Metric_Pad1.30x1.75mm_HandSolder").
Referenzbezeichner REF** in R15 geändert.
R23 hinzugefügt (Footprint "Resistor_SMD:R_1206_3216Metric_Pad1.30x1.75mm_HandSolder").
Symbolverknüpfung R15 von  nach /5314ba04-ccea-483c-b5db-c2386a78b72b aktualisiert.
R15 Eigenschaften aktualisiert.
Symbolverknüpfung R13 von  nach /caa82fb3-33b9-43cc-b704-090ccad82c17 aktualisiert.
Wert R13 von R_1206_3216Metric_Pad1.30x1.75mm_HandSolder in 1M geändert.
Referenzbezeichner REF** in R13 geändert.
R13 hinzugefügt (Footprint "Resistor_SMD:R_1206_3216Metric_Pad1.30x1.75mm_HandSolder").
Netz unconnected-(U4-PD2-Pad32) hinzufügen.
U4 Pin 32 nach unconnected-(U4-PD2-Pad32) verbunden.
R12 Pin 2 nach sb verbunden.
R12 Pin 1 nach +5V verbunden.
R12 Eigenschaften aktualisiert.
Symbolverknüpfung R12 von  nach /3e9458ed-7b90-4190-8823-2b574345fc49 aktualisiert.
Wert R12 von R_1206_3216Metric_Pad1.30x1.75mm_HandSolder in 10k geändert.
Referenzbezeichner REF** in R12 geändert.
R12 hinzugefügt (Footprint "Resistor_SMD:R_1206_3216Metric_Pad1.30x1.75mm_HandSolder").
Y1 hinzugefügt (Footprint "Crystal:Crystal_HC49-U_Vertical").
R11 Pin 2 nach +12V verbunden.
SW4 Pin 1 nach reset verbunden.
SW3 Pin 2 nach GND verbunden.
U4 Pin 9 nach sense_usb verbunden.
SW4 hinzugefügt (Footprint "SW_TS-1093C-A15_YDI").
Referenzbezeichner REF** in SW4 geändert.
Wert SW4 von SW_TS-1093C-A15_YDI in TS-1093C-A15 geändert.
Symbolverknüpfung SW4 von  nach /83439a76-3bda-4e70-b8d0-d527763e79c8 aktualisiert.
U4 Pin 8 nach Net-(U4-PB7) verbunden.
SW4 Eigenschaften aktualisiert.
SW3 Pin 1 nach u3 verbunden.
SW4 Pin 2 nach GND verbunden.
U4 Pin 7 nach Net-(U4-PB6) verbunden.
U1 hinzugefügt (Footprint "DQC0010A").
Referenzbezeichner REF** in U1 geändert.
Wert U1 von DQC0010A in TPS62175DQCR geändert.
Symbolverknüpfung U1 von  nach /e1dd3295-1df6-4203-9213-f40fdde27371 aktualisiert.
U1 Eigenschaften aktualisiert.
SW2 Pin 2 nach GND verbunden.
SW1 Pin 2 nach GND verbunden.
U4 Pin 12 nach bl_ctrl verbunden.
SW2 hinzugefügt (Footprint "SW_TS-1093C-A15_YDI").
Referenzbezeichner REF** in SW2 geändert.
Wert SW2 von SW_TS-1093C-A15_YDI in TS-1093C-A15 geändert.
Symbolverknüpfung SW2 von  nach /a3fcf73e-ec2c-4983-99b1-53bf6cd96dc5 aktualisiert.
SW2 Eigenschaften aktualisiert.
SW2 Pin 1 nach u2 verbunden.
U1 Pin 1 nach GND verbunden.
U4 Pin 11 nach analog_in verbunden.
SW3 hinzugefügt (Footprint "SW_TS-1093C-A15_YDI").
Referenzbezeichner REF** in SW3 geändert.
Wert SW3 von SW_TS-1093C-A15_YDI in TS-1093C-A15 geändert.
Symbolverknüpfung SW3 von  nach /4c2860e4-28dc-4813-b2db-d425c93b4974 aktualisiert.
U4 Pin 10 nach poti verbunden.
SW3 Eigenschaften aktualisiert.
U3 Pin 4 nach Net-(R26-Pad1) verbunden.
Referenzbezeichner REF** in U3 geändert.
Wert U3 von SOT-23-5 in LM321 geändert.
Symbolverknüpfung U3 von  nach /0d9d5432-ba39-4401-a1c2-2f33b5430d23 aktualisiert.
U3 Eigenschaften aktualisiert.
U3 Pin 1 nach Net-(U3-+) verbunden.
U3 Pin 2 nach GND verbunden.
U4 Pin 3 nach GND verbunden.
U3 Pin 3 nach Net-(U3--) verbunden.
U3 hinzugefügt (Footprint "Package_TO_SOT_SMD:SOT-23-5").
U3 Pin 5 nach +5V verbunden.
U4 Pin 2 nach sense_12v verbunden.
U4 hinzugefügt (Footprint "TQFP-32_7x7mm:QFP80P900X900X120-32N").
Referenzbezeichner REF** in U4 geändert.
Wert U4 von QFP80P900X900X120-32N in ATMEGA328P-AU geändert.
Symbolverknüpfung U4 von  nach /54e0b9cb-0b88-42a8-9ec1-4dedbac42895 aktualisiert.
U4 Pin 1 nach s_ctrl verbunden.
SW1 Pin 1 nach u1 verbunden.
U4 Pin 4 nach +5V verbunden.
U4 Pin 5 nach GND verbunden.
U1 Pin 11 nach GND verbunden.
U1 Pin 10 nach +5V verbunden.
U1 Pin 9 nach Net-(U1-SW) verbunden.
U1 Pin 8 nach +5V verbunden.
U1 Pin 7 nach unconnected-(U1-PG-Pad7) verbunden.
Netz unconnected-(U1-PG-Pad7) hinzufügen.
U1 Pin 6 nach GND verbunden.
U1 Pin 5 nach Net-(U1-FB) verbunden.
U4 Pin 6 nach +5V verbunden.
U1 Pin 4 nach unconnected-(U1-NC-Pad4) verbunden.
Netz unconnected-(U1-NC-Pad4) hinzufügen.
U1 Pin 3 nach VDC verbunden.
U1 Pin 2 nach VDC verbunden.
U4 Pin 19 nach standby verbunden.
Referenzbezeichner REF** in R25 geändert.
Wert R25 von R_1206_3216Metric_Pad1.30x1.75mm_HandSolder in 100k geändert.
Netz unconnected-(U4-AREF-Pad20) hinzufügen.
Symbolverknüpfung R25 von  nach /f08fa2e0-ee54-4518-b864-3d719686d092 aktualisiert.
R25 Eigenschaften aktualisiert.
R25 Pin 1 nach GND verbunden.
Netz Net-(U3--) hinzufügen.
R25 Pin 2 nach Net-(U3--) verbunden.
R25 hinzugefügt (Footprint "Resistor_SMD:R_1206_3216Metric_Pad1.30x1.75mm_HandSolder").
R26 hinzugefügt (Footprint "Resistor_SMD:R_1206_3216Metric_Pad1.30x1.75mm_HandSolder").
Referenzbezeichner REF** in R26 geändert.
Wert R26 von R_1206_3216Metric_Pad1.30x1.75mm_HandSolder in 56k geändert.
Symbolverknüpfung R26 von  nach /f9522751-6d88-44dd-a82e-ac4cf45e0e81 aktualisiert.
R26 Eigenschaften aktualisiert.
U4 Pin 18 nach +5V verbunden.
Netz Net-(R26-Pad1) hinzufügen.
R24 hinzugefügt (Footprint "Resistor_SMD:R_1206_3216Metric_Pad1.30x1.75mm_HandSolder").
U4 Eigenschaften aktualisiert.
Referenzbezeichner REF** in R23 geändert.
Wert R23 von R_1206_3216Metric_Pad1.30x1.75mm_HandSolder in 10k geändert.
Symbolverknüpfung R23 von  nach /66dc7613-6f5f-4752-8379-d009e3d01505 aktualisiert.
R23 Eigenschaften aktualisiert.
R23 Pin 1 nach +5V verbunden.
R23 Pin 2 nach reset verbunden.
U4 Pin 21 nach GND verbunden.
R26 Pin 1 nach Net-(R26-Pad1) verbunden.
Referenzbezeichner REF** in R24 geändert.
U4 Pin 20 nach unconnected-(U4-AREF-Pad20) verbunden.
Wert R24 von R_1206_3216Metric_Pad1.30x1.75mm_HandSolder in 1k geändert.
Symbolverknüpfung R24 von  nach /19f42d8e-7b97-46da-9695-e5765f280104 aktualisiert.
R24 Eigenschaften aktualisiert.
R24 Pin 1 nach Net-(U3-+) verbunden.
R24 Pin 2 nach sens verbunden.
R29 Pin 1 nach Net-(IC1-VDD) verbunden.
R28 Pin 1 nach VBUS verbunden.
R28 Pin 2 nach Net-(IC1-VBUS) verbunden.
U4 Pin 14 nach cs verbunden.
R29 hinzugefügt (Footprint "Resistor_SMD:R_1206_3216Metric_Pad1.30x1.75mm_HandSolder").
Referenzbezeichner REF** in R29 geändert.
Wert R29 von R_1206_3216Metric_Pad1.30x1.75mm_HandSolder in 1k geändert.
Symbolverknüpfung R29 von  nach /359f145b-7fc0-4e40-888d-b06d7f57757e aktualisiert.
R29 Eigenschaften aktualisiert.
R28 Eigenschaften aktualisiert.
R29 Pin 2 nach VBUS verbunden.
U4 Pin 13 nach dc verbunden.
SW1 hinzugefügt (Footprint "SW_TS-1093C-A15_YDI").
Referenzbezeichner REF** in SW1 geändert.
Wert SW1 von SW_TS-1093C-A15_YDI in TS-1093C-A15 geändert.
Symbolverknüpfung SW1 von  nach /65a8dd18-8399-47f8-82fe-1913048202fc aktualisiert.
SW1 Eigenschaften aktualisiert.
Netz unconnected-(U4-ADC7-Pad22) hinzufügen.
Symbolverknüpfung R28 von  nach /6e72446e-f544-4b4c-b582-c62dc1aff4b4 aktualisiert.
Wert R28 von R_1206_3216Metric_Pad1.30x1.75mm_HandSolder in 10k geändert.
Referenzbezeichner REF** in R28 geändert.
R28 hinzugefügt (Footprint "Resistor_SMD:R_1206_3216Metric_Pad1.30x1.75mm_HandSolder").
U4 Pin 15 nach mois verbunden.
R27 Pin 2 nach Net-(R26-Pad1) verbunden.
R27 Pin 1 nach analog_in verbunden.
R27 Eigenschaften aktualisiert.
U4 Pin 16 nach miso verbunden.
Symbolverknüpfung R27 von  nach /e5ad9d36-4f9f-4852-9455-0aad34eadaff aktualisiert.
Wert R27 von R_1206_3216Metric_Pad1.30x1.75mm_HandSolder in 1k geändert.
Referenzbezeichner REF** in R27 geändert.
R27 hinzugefügt (Footprint "Resistor_SMD:R_1206_3216Metric_Pad1.30x1.75mm_HandSolder").
U4 Pin 17 nach sck verbunden.
R26 Pin 2 nach Net-(U3--) verbunden.
IC1 Pin 3 nach GND verbunden.
C13 Pin 1 nach Net-(IC1-VDD) verbunden.
C13 Pin 2 nach GND verbunden.
IC1 hinzugefügt (Footprint "SOP100P600X180-11N").
Referenzbezeichner IC** in IC1 geändert.
Wert IC1 von SOP100P600X180-11N in CH224K geändert.
Symbolverknüpfung IC1 von  nach /1e3282ea-4c64-4da3-a28f-2a7e23b3db92 aktualisiert.
IC1 Eigenschaften aktualisiert.
IC1 Pin 1 nach Net-(IC1-VDD) verbunden.
IC1 Pin 2 nach GND verbunden.
Netz Net-(IC1-VDD) hinzufügen.
Netz dp hinzufügen.
IC1 Pin 4 nach dp verbunden.
Netz dm hinzufügen.
IC1 Pin 5 nach dm verbunden.
IC1 Pin 6 nach cc1 verbunden.
IC1 Pin 7 nach cc2 verbunden.
Netz Net-(IC1-VBUS) hinzufügen.
IC1 Pin 8 nach Net-(IC1-VBUS) verbunden.
Symbolverknüpfung C12 von  nach /05b538df-7f25-4dc8-85c8-4cfac3218f00 aktualisiert.
Wert C11 von R_1206_3216Metric_Pad1.30x1.75mm_HandSolder in 100n geändert.
Symbolverknüpfung C11 von  nach /81a7c767-18ae-4a7c-b5d0-68580ea9b1f1 aktualisiert.
C11 Eigenschaften aktualisiert.
C11 Pin 1 nach GND verbunden.
C11 Pin 2 nach analog_in verbunden.
C12 hinzugefügt (Footprint "Resistor_SMD:R_1206_3216Metric_Pad1.30x1.75mm_HandSolder").
Referenzbezeichner REF** in C12 geändert.
Wert C12 von R_1206_3216Metric_Pad1.30x1.75mm_HandSolder in 100n geändert.
Netz pd-cfg hinzufügen.
C12 Eigenschaften aktualisiert.
C12 Pin 1 nach GND verbunden.
C12 Pin 2 nach +5V verbunden.
C13 hinzugefügt (Footprint "Resistor_SMD:R_1206_3216Metric_Pad1.30x1.75mm_HandSolder").
Referenzbezeichner REF** in C13 geändert.
Wert C13 von R_1206_3216Metric_Pad1.30x1.75mm_HandSolder in 1u geändert.
Symbolverknüpfung C13 von  nach /cbc453b1-1df7-4592-afb9-0c3b0d20fae2 aktualisiert.
C13 Eigenschaften aktualisiert.
J2 Eigenschaften aktualisiert.
J1 Pin 6 nach Net-(J1-Pin_6) verbunden.
Netz Net-(J1-Pin_7) hinzufügen.
J1 Pin 7 nach Net-(J1-Pin_7) verbunden.
Netz Net-(J1-Pin_8) hinzufügen.
J1 Pin 8 nach Net-(J1-Pin_8) verbunden.
J2 hinzugefügt (Footprint "DC00520A").
Referenzbezeichner J** in J2 geändert.
Wert J2 von DC00520A in DC-005-20A geändert.
Symbolverknüpfung J2 von  nach /0900a351-6f33-45a2-9e64-aa955a75176e aktualisiert.
Netz Net-(J1-Pin_6) hinzufügen.
J2 Pin 1 nach +12V verbunden.
J2 Pin 2 nach GND verbunden.
J2 Pin 3 nach GND verbunden.
J4 hinzugefügt (Footprint "Connector_IDC:IDC-Header_2x03_P2.54mm_Vertical").
Referenzbezeichner REF** in J4 geändert.
Wert J4 von IDC-Header_2x03_P2.54mm_Vertical in Conn_02x03_Top_Bottom geändert.
Symbolverknüpfung J4 von  nach /b8025169-e128-43a5-aa34-f5d2870f4190 aktualisiert.
J4 Eigenschaften aktualisiert.
Symbolverknüpfung J1 von  nach /0442e453-5c91-4885-bab8-bf2a17bcbcd2 aktualisiert.
IC1 Pin 9 nach pd-cfg verbunden.
Netz unconnected-(IC1-PG-Pad10) hinzufügen.
IC1 Pin 10 nach unconnected-(IC1-PG-Pad10) verbunden.
Netz unconnected-(IC1-GND-Pad11) hinzufügen.
IC1 Pin 11 nach unconnected-(IC1-GND-Pad11) verbunden.
J1 hinzugefügt (Footprint "Connector_Molex:Molex_SL_171971-0008_1x08_P2.54mm_Vertical").
Referenzbezeichner REF** in J1 geändert.
Wert J1 von Molex_SL_171971-0008_1x08_P2.54mm_Vertical in Conn_01x08_Pin geändert.
Referenzbezeichner REF** in C11 geändert.
J1 Eigenschaften aktualisiert.
J1 Pin 1 nach GND verbunden.
J1 Pin 2 nach bl verbunden.
J1 Pin 3 nach +5V verbunden.
Netz Net-(J1-Pin_4) hinzufügen.
J1 Pin 4 nach Net-(J1-Pin_4) verbunden.
Netz Net-(J1-Pin_5) hinzufügen.
J1 Pin 5 nach Net-(J1-Pin_5) verbunden.
C5 hinzugefügt (Footprint "Resistor_SMD:R_1206_3216Metric_Pad1.30x1.75mm_HandSolder").
C3 Pin 1 nach GND verbunden.
C3 Pin 2 nach cc1 verbunden.
C4 hinzugefügt (Footprint "Resistor_SMD:R_1206_3216Metric_Pad1.30x1.75mm_HandSolder").
Referenzbezeichner REF** in C4 geändert.
Wert C4 von R_1206_3216Metric_Pad1.30x1.75mm_HandSolder in 330p geändert.
Symbolverknüpfung C4 von  nach /7f0e6613-173c-4fb8-a80a-371f58dff298 aktualisiert.
C4 Eigenschaften aktualisiert.
C4 Pin 1 nach GND verbunden.
C4 Pin 2 nach cc2 verbunden.
C3 Eigenschaften aktualisiert.
Referenzbezeichner REF** in C5 geändert.
Wert C5 von R_1206_3216Metric_Pad1.30x1.75mm_HandSolder in 10u geändert.
Symbolverknüpfung C5 von  nach /e9543b11-4a7b-496c-b8be-1f4b3177adb2 aktualisiert.
C5 Eigenschaften aktualisiert.
C5 Pin 1 nach GND verbunden.
C5 Pin 2 nach +5V verbunden.
C6 hinzugefügt (Footprint "Resistor_SMD:R_1206_3216Metric_Pad1.30x1.75mm_HandSolder").
Referenzbezeichner REF** in C6 geändert.
Wert C2 von R_1206_3216Metric_Pad1.30x1.75mm_HandSolder in 100n geändert.
Referenzbezeichner REF** in C1 geändert.
Wert C1 von R_1206_3216Metric_Pad1.30x1.75mm_HandSolder in 100n geändert.
Symbolverknüpfung C1 von  nach /7805d30f-2c1b-44cc-96db-40e41de1a9da aktualisiert.
C1 Eigenschaften aktualisiert.
C1 Pin 1 nach GND verbunden.
C1 Pin 2 nach +5V verbunden.
C2 hinzugefügt (Footprint "Resistor_SMD:R_1206_3216Metric_Pad1.30x1.75mm_HandSolder").
Referenzbezeichner REF** in C2 geändert.
Wert C6 von R_1206_3216Metric_Pad1.30x1.75mm_HandSolder in 10u geändert.
Symbolverknüpfung C2 von  nach /b770ee6d-2e47-40db-b1a0-11abefe4ceec aktualisiert.
C2 Eigenschaften aktualisiert.
C2 Pin 1 nach GND verbunden.
C2 Pin 2 nach VBUS verbunden.
C3 hinzugefügt (Footprint "Resistor_SMD:R_1206_3216Metric_Pad1.30x1.75mm_HandSolder").
Referenzbezeichner REF** in C3 geändert.
Wert C3 von R_1206_3216Metric_Pad1.30x1.75mm_HandSolder in 330p geändert.
Symbolverknüpfung C3 von  nach /48fb3533-24e0-4bcc-a18d-e6dda8bb1453 aktualisiert.
C10 hinzugefügt (Footprint "Resistor_SMD:R_1206_3216Metric_Pad1.30x1.75mm_HandSolder").
C8 Pin 2 nach Net-(U4-PB6) verbunden.
C9 hinzugefügt (Footprint "Resistor_SMD:R_1206_3216Metric_Pad1.30x1.75mm_HandSolder").
Referenzbezeichner REF** in C9 geändert.
Wert C9 von R_1206_3216Metric_Pad1.30x1.75mm_HandSolder in 22p geändert.
Symbolverknüpfung C9 von  nach /47e7af46-184b-4b5d-99a4-aec2231401e5 aktualisiert.
C9 Eigenschaften aktualisiert.
C9 Pin 1 nach GND verbunden.
Netz Net-(U4-PB7) hinzufügen.
C9 Pin 2 nach Net-(U4-PB7) verbunden.
Netz Net-(U4-PB6) hinzufügen.
Referenzbezeichner REF** in C10 geändert.
Wert C10 von R_1206_3216Metric_Pad1.30x1.75mm_HandSolder in 100n geändert.
Symbolverknüpfung C10 von  nach /98a93818-d3e7-46e3-a872-315035eecca3 aktualisiert.
C10 Eigenschaften aktualisiert.
C10 Pin 1 nach GND verbunden.
Netz Net-(U3-+) hinzufügen.
C10 Pin 2 nach Net-(U3-+) verbunden.
C11 hinzugefügt (Footprint "Resistor_SMD:R_1206_3216Metric_Pad1.30x1.75mm_HandSolder").
C7 Eigenschaften aktualisiert.
Symbolverknüpfung C6 von  nach /334bc59e-ac32-498a-802d-6e7ee3f96569 aktualisiert.
C6 Eigenschaften aktualisiert.
C6 Pin 1 nach GND verbunden.
C6 Pin 2 nach +5V verbunden.
C7 hinzugefügt (Footprint "Resistor_SMD:R_1206_3216Metric_Pad1.30x1.75mm_HandSolder").
Referenzbezeichner REF** in C7 geändert.
Wert C7 von R_1206_3216Metric_Pad1.30x1.75mm_HandSolder in 10u geändert.
Symbolverknüpfung C7 von  nach /f8502e95-4cd2-42d5-931d-89d07d23f4e1 aktualisiert.
R7 Pin 1 nach +5V verbunden.
C7 Pin 1 nach GND verbunden.
C7 Pin 2 nach +5V verbunden.
C8 hinzugefügt (Footprint "Resistor_SMD:R_1206_3216Metric_Pad1.30x1.75mm_HandSolder").
Referenzbezeichner REF** in C8 geändert.
Wert C8 von R_1206_3216Metric_Pad1.30x1.75mm_HandSolder in 22p geändert.
Symbolverknüpfung C8 von  nach /1f851b23-fa07-40a0-a4a2-922ed9239156 aktualisiert.
C8 Eigenschaften aktualisiert.
C8 Pin 1 nach GND verbunden.
Q3 Pin 3 nach +5V verbunden.
Q2 Pin 7 nach output_power verbunden.
Q2 Pin 8 nach output_power verbunden.
Q3 hinzugefügt (Footprint "Package_TO_SOT_SMD:SOT-23").
Referenzbezeichner REF** in Q3 geändert.
Wert Q3 von SOT-23 in BSN20 geändert.
Symbolverknüpfung Q3 von  nach /881231dc-2f75-47ba-a666-7d34e6728aca aktualisiert.
Q3 Eigenschaften aktualisiert.
Q3 Pin 1 nach Net-(Q3-G) verbunden.
Q3 Pin 2 nach bl verbunden.
Q2 Pin 6 nach output_power verbunden.
R1 hinzugefügt (Footprint "Resistor_SMD:R_1206_3216Metric_Pad1.30x1.75mm_HandSolder").
Referenzbezeichner REF** in R1 geändert.
Wert R1 von R_1206_3216Metric_Pad1.30x1.75mm_HandSolder in 10k geändert.
Symbolverknüpfung R1 von  nach /9492370a-3db0-4a60-b4d8-1f57e29d5f89 aktualisiert.
R1 Eigenschaften aktualisiert.
R1 Pin 1 nach +5V verbunden.
R1 Pin 2 nach u1 verbunden.
R2 hinzugefügt (Footprint "Resistor_SMD:R_1206_3216Metric_Pad1.30x1.75mm_HandSolder").
Referenzbezeichner REF** in R2 geändert.
Referenzbezeichner REF** in Q2 geändert.
Q1 hinzugefügt (Footprint "Package_TO_SOT_SMD:SOT-23").
Referenzbezeichner REF** in Q1 geändert.
Wert Q1 von SOT-23 in BSN20 geändert.
Symbolverknüpfung Q1 von  nach /364c9cc1-d75f-4268-ac9c-6dfe1e99c741 aktualisiert.
Q1 Eigenschaften aktualisiert.
Q1 Pin 1 nach Net-(Q1-G) verbunden.
Q1 Pin 2 nach GND verbunden.
Q1 Pin 3 nach +12V verbunden.
Q2 hinzugefügt (Footprint "SO-8_IRF741_INF").
Wert R2 von R_1206_3216Metric_Pad1.30x1.75mm_HandSolder in 1k geändert.
Wert Q2 von SO-8_IRF741_INF in IRF7416TRPBF geändert.
Symbolverknüpfung Q2 von  nach /71fee9ef-dca7-43a5-8325-99afbcb8799e aktualisiert.
Q2 Eigenschaften aktualisiert.
Q2 Pin 1 nach +12V verbunden.
Q2 Pin 2 nach +12V verbunden.
Q2 Pin 3 nach +12V verbunden.
Q2 Pin 4 nach Net-(Q2-G) verbunden.
Q2 Pin 5 nach output_power verbunden.
Symbolverknüpfung R6 von  nach /90b5ea00-f45b-4b3b-87bc-4ad40c825a8c aktualisiert.
Referenzbezeichner REF** in R5 geändert.
Wert R5 von R_1206_3216Metric_Pad1.30x1.75mm_HandSolder in 10k geändert.
Symbolverknüpfung R5 von  nach /5dce2ced-ed62-405c-b146-ff77fdd53113 aktualisiert.
R5 Eigenschaften aktualisiert.
R5 Pin 1 nach GND verbunden.
R5 Pin 2 nach Net-(Q1-G) verbunden.
R6 hinzugefügt (Footprint "Resistor_SMD:R_1206_3216Metric_Pad1.30x1.75mm_HandSolder").
Referenzbezeichner REF** in R6 geändert.
Wert R6 von R_1206_3216Metric_Pad1.30x1.75mm_HandSolder in 1k geändert.
R5 hinzugefügt (Footprint "Resistor_SMD:R_1206_3216Metric_Pad1.30x1.75mm_HandSolder").
R6 Eigenschaften aktualisiert.
R6 Pin 1 nach mosi verbunden.
R6 Pin 2 nach Net-(J1-Pin_5) verbunden.
R7 hinzugefügt (Footprint "Resistor_SMD:R_1206_3216Metric_Pad1.30x1.75mm_HandSolder").
Referenzbezeichner REF** in R7 geändert.
Wert R7 von R_1206_3216Metric_Pad1.30x1.75mm_HandSolder in 10k geändert.
Symbolverknüpfung R7 von  nach /66cbc6cb-6a1f-4435-bfa0-cb732f9553b2 aktualisiert.
R7 Eigenschaften aktualisiert.
R7 Pin 2 nach u2 verbunden.
R3 Pin 1 nach Net-(Q1-G) verbunden.
Symbolverknüpfung R2 von  nach /01d64ece-0598-4e08-8348-63caf319faa9 aktualisiert.
R2 Eigenschaften aktualisiert.
R2 Pin 1 nach sck verbunden.
R2 Pin 2 nach Net-(J1-Pin_4) verbunden.
R3 hinzugefügt (Footprint "Resistor_SMD:R_1206_3216Metric_Pad1.30x1.75mm_HandSolder").
Referenzbezeichner REF** in R3 geändert.
Wert R3 von R_1206_3216Metric_Pad1.30x1.75mm_HandSolder in 1k geändert.
Symbolverknüpfung R3 von  nach /3a65f0fe-04a5-4362-9d83-2a49577c69aa aktualisiert.
R3 Eigenschaften aktualisiert.
J4 Pin 2 nach VDC verbunden.
R3 Pin 2 nach s_ctrl verbunden.
R4 hinzugefügt (Footprint "Resistor_SMD:R_1206_3216Metric_Pad1.30x1.75mm_HandSolder").
Referenzbezeichner REF** in R4 geändert.
Wert R4 von R_1206_3216Metric_Pad1.30x1.75mm_HandSolder in 1k geändert.
Symbolverknüpfung R4 von  nach /a55bc506-54c5-4a37-b41f-512d1d6a20e8 aktualisiert.
R4 Eigenschaften aktualisiert.
R4 Pin 1 nach +5V verbunden.
R4 Pin 2 nach Net-(J1-Pin_8) verbunden.
J7 Eigenschaften aktualisiert.
J6 Pin 2 nach sck verbunden.
J6 Pin 3 nach reset verbunden.
J6 Pin 4 nach GND verbunden.
J6 Pin 5 nach mosi verbunden.
J6 Pin 6 nach +5V verbunden.
J7 hinzugefügt (Footprint "PJ-313D-B-SMT_XKB").
Referenzbezeichner REF** in J7 geändert.
Wert J7 von PJ-313D-B-SMT_XKB in PJ-313D-B-SMT geändert.
Symbolverknüpfung J7 von  nach /54737c57-373b-4b2b-98a7-3bc4d6b70908 aktualisiert.
J6 Pin 1 nach miso verbunden.
J7 Pin 1A nach GND verbunden.
J7 Pin 1B nach GND verbunden.
J7 Pin 2A nach output_power verbunden.
J7 Pin 2B nach output_power verbunden.
J7 Pin 3A nach sens verbunden.
J7 Pin 3B nach sens verbunden.
J8 hinzugefügt (Footprint "CONN12_B-7004_GSW").
Referenzbezeichner REF** in J8 geändert.
Wert J8 von CONN12_B-7004_GSW in GT-USB-7004 geändert.
J5 Eigenschaften aktualisiert.
J4 Pin 1 nach VBUS verbunden.
J4 Pin 3 nach +12V verbunden.
J4 Pin 4 nach sense_usb verbunden.
J4 Pin 5 nach +5V verbunden.
J4 Pin 6 nach sense_12v verbunden.
J5 hinzugefügt (Footprint "Connector:FanPinHeader_1x04_P2.54mm_Vertical").
Referenzbezeichner REF** in J5 geändert.
Wert J5 von FanPinHeader_1x04_P2.54mm_Vertical in Conn_01x04 geändert.
Symbolverknüpfung J5 von  nach /eccd7a53-2905-49e7-85d7-5076b7284962 aktualisiert.
Netz Net-(U1-SW) hinzufügen.
J5 Pin 1 nach GND verbunden.
J5 Pin 2 nach poti verbunden.
J5 Pin 3 nach sb verbunden.
J5 Pin 4 nach +5V verbunden.
J6 hinzugefügt (Footprint "Connector_IDC:IDC-Header_2x03_P2.54mm_Vertical").
Referenzbezeichner REF** in J6 geändert.
Wert J6 von IDC-Header_2x03_P2.54mm_Vertical in Conn_02x03_Counter_Clockwise geändert.
Symbolverknüpfung J6 von  nach /b39e3462-b219-4999-9701-ad3137c62a80 aktualisiert.
J6 Eigenschaften aktualisiert.
L1 Pin 2 nach Net-(U1-SW) verbunden.
L1 hinzugefügt (Footprint "IND_NLCV32T_TDK").
Referenzbezeichner REF** in L1 geändert.
Wert L1 von IND_NLCV32T_TDK in 10u geändert.
Symbolverknüpfung L1 von  nach /a6118cc3-39ed-4654-a961-657cb32948df aktualisiert.
L1 Eigenschaften aktualisiert.
L1 Pin 1 nach +5V verbunden.
J8 Eigenschaften aktualisiert.
Symbolverknüpfung J8 von  nach /5ff4f302-2384-4afd-b26e-4d8f4751c2bf aktualisiert.
Warnung: Kein Netz für Symbol J8 Pin 2 gefunden.
Warnung: Kein Netz für Symbol J8 Pin 20 gefunden.
Warnung: Kein Netz für Symbol U1 Pin V gefunden.
Warnung: Kein Netz für Symbol U1 Pin V gefunden.
Warnung: Kein Netz für Symbol U1 Pin V gefunden.
Warnung: Kein Netz für Symbol J8 Pin 1 gefunden.
Warnung: Kein Netz für Symbol J8 Pin 18 gefunden.
Warnung: Kein Netz für Symbol SW1 Pin 4 gefunden.
Warnung: Kein Netz für Symbol SW4 Pin 3 gefunden.
Warnung: Kein Netz für Symbol SW4 Pin 4 gefunden.
Warnung: Via mit unbekannten Netz (sda) verbunden.
Warnung: Via mit unbekannten Netz (sda) verbunden.
Warnung: Via mit unbekannten Netz (unconnected-(U1-PD0-Pad30)) verbunden.
Warnung: Via mit unbekannten Netz (unconnected-(U1-PD0-Pad30)) verbunden.
Warnung: Via mit unbekannten Netz (unconnected-(U1-PD1-Pad31)) verbunden.
Warnung: Kein Netz für Symbol J8 Pin 9 gefunden.
Warnung: Kein Netz für Symbol SW1 Pin 3 gefunden.
Warnung: Kein Netz für Symbol J8 Pin 16 gefunden.
Warnung: Kein Netz für Symbol J8 Pin 15 gefunden.
Warnung: Kein Netz für Symbol J8 Pin 14 gefunden.
Warnung: Kein Netz für Symbol J8 Pin 3 gefunden.
Warnung: Kein Netz für Symbol J8 Pin 13 gefunden.
Warnung: Kein Netz für Symbol J8 Pin 4 gefunden.
Warnung: Kein Netz für Symbol SW2 Pin 3 gefunden.
Warnung: Kein Netz für Symbol SW2 Pin 4 gefunden.
Warnung: Kein Netz für Symbol J8 Pin 5 gefunden.
Warnung: Kein Netz für Symbol J8 Pin 6 gefunden.
Warnung: Kein Netz für Symbol J8 Pin 12 gefunden.
Warnung: Kein Netz für Symbol J8 Pin 17 gefunden.
Warnung: Kein Netz für Symbol SW3 Pin 4 gefunden.
Warnung: Kein Netz für Symbol SW3 Pin 3 gefunden.
Warnung: Kein Netz für Symbol J8 Pin 10 gefunden.
Warnung: Kein Netz für Symbol J8 Pin 19 gefunden.
Warnung: Kein Netz für Symbol J8 Pin 8 gefunden.
Warnung: Kein Netz für Symbol J8 Pin 7 gefunden.
Warnung: Kein Netz für Symbol J8 Pin 11 gefunden.
Fehler: J8 Pad B8 nicht gefunden in CONN12_B-7004_GSW:CONN12_B-7004_GSW.
Fehler: J8 Pad A8 nicht gefunden in CONN12_B-7004_GSW:CONN12_B-7004_GSW.
Fehler: J8 Pad B6 nicht gefunden in CONN12_B-7004_GSW:CONN12_B-7004_GSW.
Fehler: J8 Pad A6 nicht gefunden in CONN12_B-7004_GSW:CONN12_B-7004_GSW.
Fehler: J8 Pad B7 nicht gefunden in CONN12_B-7004_GSW:CONN12_B-7004_GSW.
Fehler: J8 Pad A7 nicht gefunden in CONN12_B-7004_GSW:CONN12_B-7004_GSW.
Fehler: J8 Pad B5 nicht gefunden in CONN12_B-7004_GSW:CONN12_B-7004_GSW.
Fehler: J8 Pad A5 nicht gefunden in CONN12_B-7004_GSW:CONN12_B-7004_GSW.
Fehler: J8 Pad B9 nicht gefunden in CONN12_B-7004_GSW:CONN12_B-7004_GSW.
Fehler: J8 Pad B4 nicht gefunden in CONN12_B-7004_GSW:CONN12_B-7004_GSW.
Fehler: J8 Pad A9 nicht gefunden in CONN12_B-7004_GSW:CONN12_B-7004_GSW.
Fehler: J8 Pad A4 nicht gefunden in CONN12_B-7004_GSW:CONN12_B-7004_GSW.
Fehler: J8 Pad B12 nicht gefunden in CONN12_B-7004_GSW:CONN12_B-7004_GSW.
Fehler: J8 Pad B1 nicht gefunden in CONN12_B-7004_GSW:CONN12_B-7004_GSW.
Fehler: J8 Pad A12 nicht gefunden in CONN12_B-7004_GSW:CONN12_B-7004_GSW.
Fehler: J8 Pad A1 nicht gefunden in CONN12_B-7004_GSW:CONN12_B-7004_GSW.

Hinweis: Warnungen insgesamt: 36, Fehler insgesamt: 16.

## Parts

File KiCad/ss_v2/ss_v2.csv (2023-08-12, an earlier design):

# | Reference | Qty | Value | Footprint | DNP | LCSC
1 | C1, C2 | 2 | 22p | Resistor_SMD:R_1206_3216Metric_Pad1.30x1.75mm_HandSolder |  | C1896
2 | C3, C4, C5, C11, C12 | 5 | 100n | Resistor_SMD:R_1206_3216Metric_Pad1.30x1.75mm_HandSolder |  | C527347
3 | C6, C7, C8 | 3 | 10u | Resistor_SMD:R_1206_3216Metric_Pad1.30x1.75mm_HandSolder |  | C9807
4 | C9, C10 | 2 | 330p | Resistor_SMD:R_1206_3216Metric_Pad1.30x1.75mm_HandSolder |  | C5186843
5 | J1 | 1 | PJ-313D-B-SMT | PJ-313D-B-SMT_XKB |  | C725771
6 | J2 | 1 | UJC-HP-M-G-5-MSMT-TR | UJCHPMG5MSMTTR |  | MOUSER! | https://www.mouser.de/ProductDetail/CUI-Devices/UJC-HP-M-G-5-MSMT-TR?qs=vvQtp7zwQdNoSiAt%2Fa4qvA%3D%3D
7 | J3 | 1 | DC-005-20A | DC00520A |  | C130239
8 | J4, J5 | 1 | Conn_02x03_Top_Bottom | Connector_IDC:IDC-Header_2x03_P2.54mm_Vertical |  | C706893
10 | J6 | 1 | Conn_01x08_Pin | Connector_Molex:Molex_SL_171971-0008_1x08_P2.54mm_Vertical |  | C492407
11 | J7 | 1 | Conn_01x04 | Connector:FanPinHeader_1x04_P2.54mm_Vertical |  | C2691448
12 | L1 | 1 | 10u | IND_NLCV32T_TDK |  | C295195
13 | Q1, Q3 | 2 | BSN20 | Package_TO_SOT_SMD:SOT-23 |  | C155343
14 | Q2 | 1 | IRF7416TRPBF | SO-8_IRF741_INF |  | C3000
15 | R1 | 1 | 100k | Resistor_SMD:R_1206_3216Metric_Pad1.30x1.75mm_HandSolder |  | C17900
16 | R2 | 1 | 56k | Resistor_SMD:R_1206_3216Metric_Pad1.30x1.75mm_HandSolder |  | C18029
17 | R3, R4, R8, R9, R10, R15, R16, R17, R18, R19 | 10 | 1k | Resistor_SMD:R_1206_3216Metric_Pad1.30x1.75mm_HandSolder |  | C4410
18 | R5, R20 | 2 | 1M | Resistor_SMD:R_1206_3216Metric_Pad1.30x1.75mm_HandSolder |  | C17927
19 | R6, R7, R21, R22, R23, R24, R25, R26, R27 | 9 | 10k | Resistor_SMD:R_1206_3216Metric_Pad1.30x1.75mm_HandSolder |  | C17902
20 | R11 | 1 | 270k | Resistor_SMD:R_1206_3216Metric_Pad1.30x1.75mm_HandSolder |  | C17940
21 | R12 | 1 | 51k | Resistor_SMD:R_1206_3216Metric_Pad1.30x1.75mm_HandSolder |  | C86344
22 | R13, R14 | 2 | 2k | Resistor_SMD:R_1206_3216Metric_Pad1.30x1.75mm_HandSolder |  | C17944
23 | SW1, SW2, SW3, SW4 | 4 | TS-1093C-A15 | SW_TS-1093C-A15_YDI |  | C2689824
24 | U1 | 1 | ATMEGA328P-AU | digikey-footprints:TQFP-32_7x7mm |  | C14877
25 | U2 | 1 | LM321 | Package_TO_SOT_SMD:SOT-23-5 |  | C471859
26 | U3 | 1 | TPS62125DSG | Package_SON:WSON-8-1EP_2x2mm_P0.5mm_EP0.9x1.6mm_ThermalVias |  | C32097 | Wurde auf 10-Pin geändert!
27 | U4 | 1 | FUSB302B10MPX | QFN50P250X250X80-15N |  | C891305
28 | Y1 | 1 | Crystal | Crystal:Crystal_HC49-U_Vertical |  | C16212

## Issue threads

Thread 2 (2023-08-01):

Lötkolben ist nicht Drahtlos

scmost, 2023-08-01:

HeinzAlberto, 2023-08-07:
Was halten wir davon? -> https://www.aliexpress.us/item/1005005770533692.html

scmost, 2023-08-07:
Was ich daran mag:
1. Wechselbare Lötspitzen, besonders, dass es sich um 3,5mm Klinken handelt
2. Möglichkeit die Software up zu daten
3. USB-C

Was ich daran nicht mag:
1. Lötkolben muss exakt in die Position gelegt werden, damit er geladen wird => Gibt es einen Verpolschutz?
2. Plastik der Lötstation kann beschädiggt werden, wenn der Lötkolben falsch eingelegt wird
3. Die Verarbeitung sieht finde ich schlecht aus
4. Finde das HMI etwas zu minimal, mit 2 Buttons und einem Drehrad => wirkt, als wird zum Einstellen verschiedener Parameter die Bluetooth-Verbindung benötigt
5. Lötkolben wirkt groß => Wenn Lötkolben in der Station kann ich mir vorstellen, dass Aufgrund des Hebels die Halterung verschleißt
6. Finde die Möglichkeit den Lötkolben direkt mit USB zu laden überflüssig
7. Es wurde ein 750F Super Cap Verbaut, stelle mir den überdimmensioniert vor, denke 2 Min bei voller Leistung sollte reichen

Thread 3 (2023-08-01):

Lötkolben sleep

scmost, 2023-08-01:
Lötkolben geht in den sleep sofern er in der Halterung ist

HeinzAlberto, 2023-08-12:
PCB bekommt "Standby-Pin", der über 10k gegen 5V  (R45) oder gegen GND (R26) gepulled werden kann.

Closed 2023-08-12.

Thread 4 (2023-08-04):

Lötstatsion besitzt keine Sicherung

scmost, 2023-08-04:
Einbau einer Sicherung, für einen Fehlerfall

HeinzAlberto, 2023-08-05:
Okay, das ist sinnvoll. SMD Sicherung okay?

HeinzAlberto, 2023-08-05:
Oder SMD Feinsicherung in einer Halterung?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

scmost, 2023-08-06:
Würde nen Haltermachen, da wenn die Sicherung ausgelößt hat, die Lötstation evtl. nicht mehr betrieben werden kann xD. Bin aber für beides offen.

HeinzAlberto, 2023-08-07:
Das mit der Halterung gefällt mir auch besser! Dann machen wir das.

HeinzAlberto, 2023-08-12:
Würde diese verbauen (3A): https://www.lcsc.com/product-detail/Fuses_Littelfuse-0154003-DR_C206912.html

Closed 2023-08-14.

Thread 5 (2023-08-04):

Lötstation besitz keinen Anschluss für ESD-Schutz

scmost, 2023-08-04:

HeinzAlberto, 2023-08-05:
Ja, aber woran sollte man sie verbinden? Wir können natürlich eine Buchse vorne und hinten einbauen, müssen jedoch bedenken, dass sie über die Stromversorgung nicht mit Erde verbunden ist. Halte den ESD-Schutz daher für schwierig umsetzbar und bin mir nicht über die Sinnhaftigkeit sicher.

scmost, 2023-08-06:
Anschluss an GND?
Ist zwar kein Erdungsanschluss, allerdings kann dennoch eine Ladung darüber abgebaut werden

HeinzAlberto, 2023-08-07:
GND können wir machen, müssen uns nur überlegen, wo wir ihn hin packen. Wir könnten auf der Platine ein Pad zum anlöten anlegen.

Closed 2023-08-12.

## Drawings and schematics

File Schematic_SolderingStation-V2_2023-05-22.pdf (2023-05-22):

# Spannungsversorgung uC und Lasttreiber

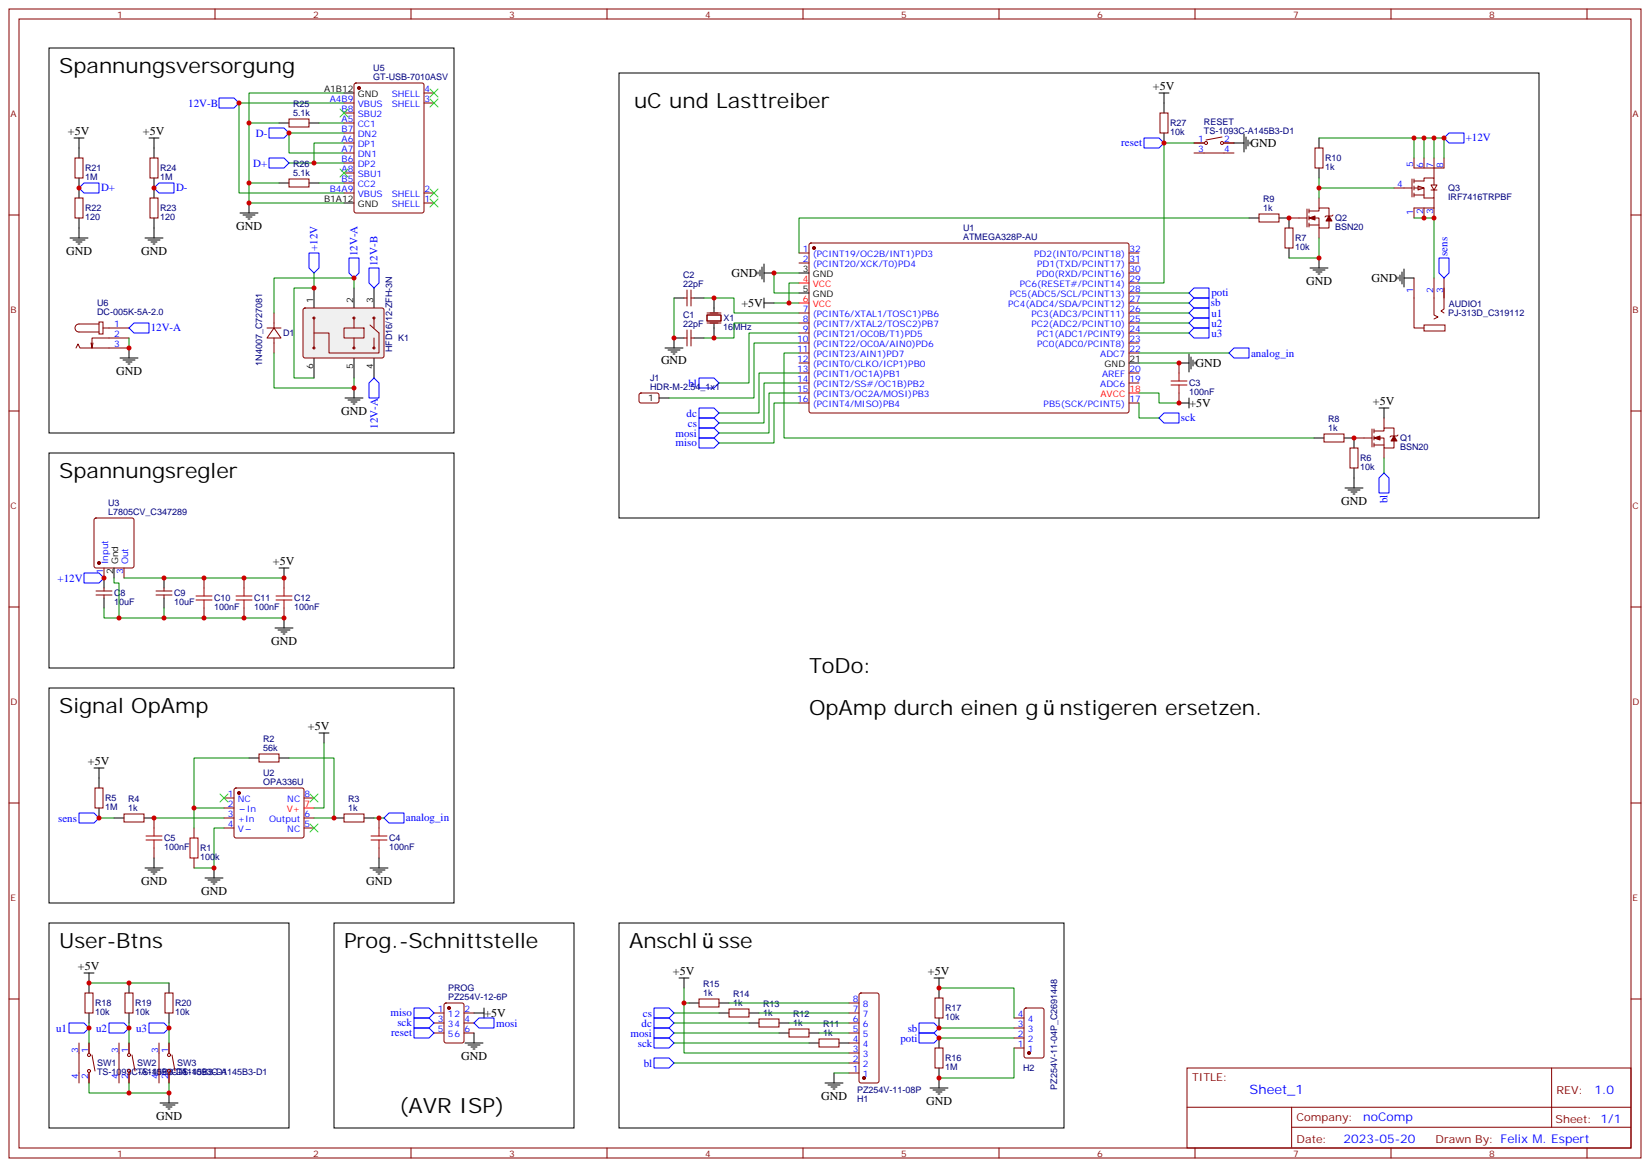
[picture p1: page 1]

ToDo:
OpAmp durch einen g nstigeren ersetzen.

Drawn By: Felix M. Espert

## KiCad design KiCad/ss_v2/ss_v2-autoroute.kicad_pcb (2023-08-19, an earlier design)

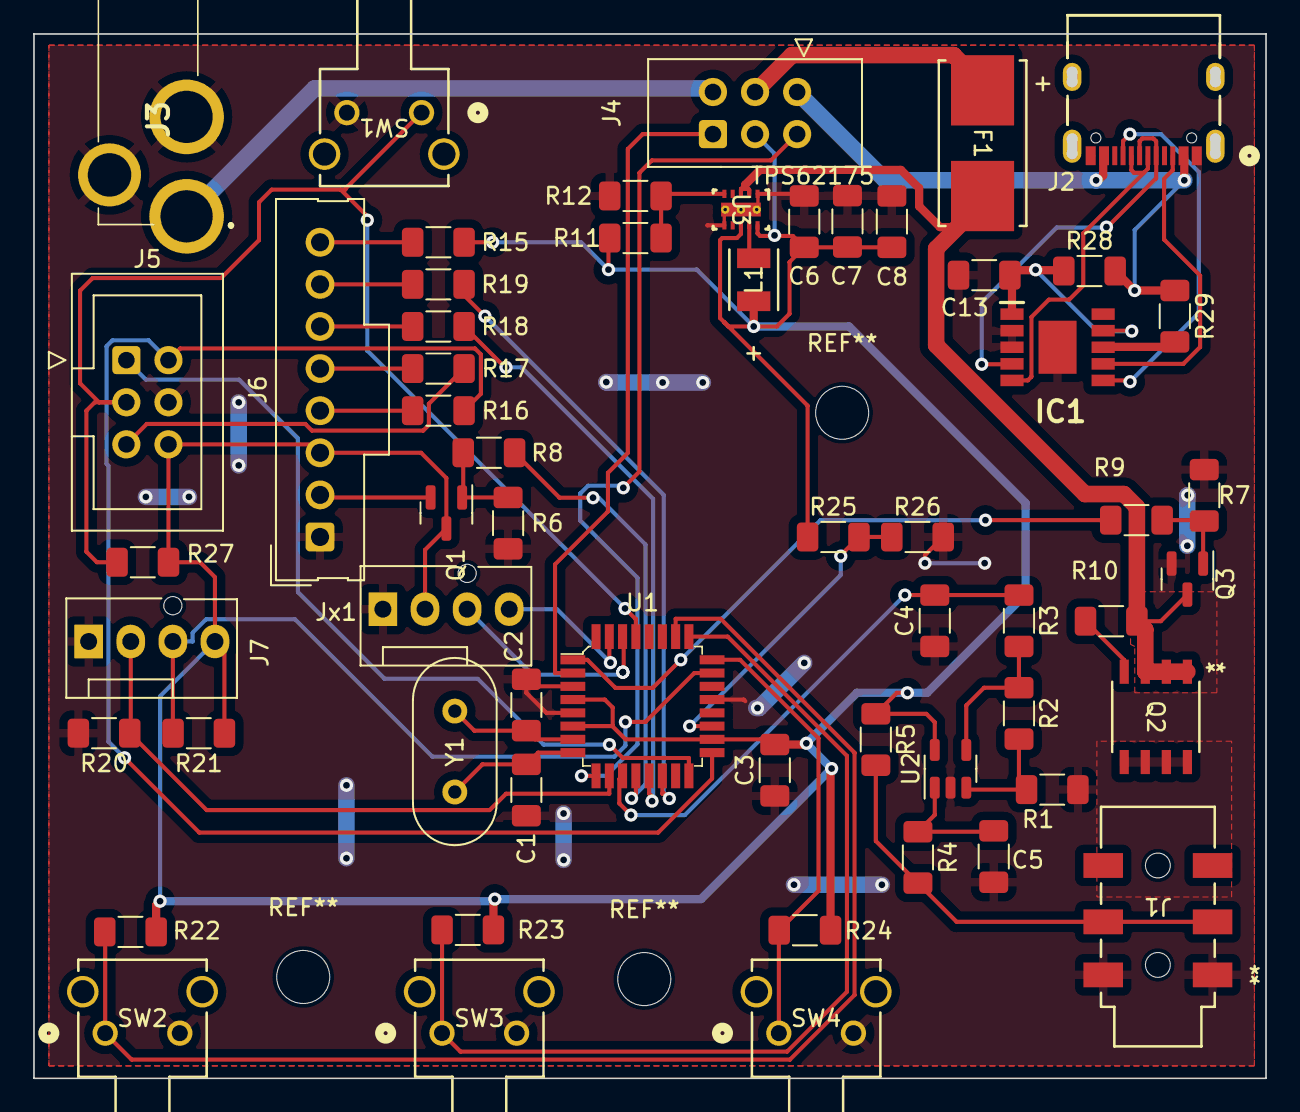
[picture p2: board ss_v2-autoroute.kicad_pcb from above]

Board: 2 copper layers, 74.3 x 63.0 mm, 58 parts (0 on the bottom side), 47 nets.

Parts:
C1, C2: 22p; R_1206_3216Metric_Pad1.30x1.75mm_HandSolder
C3, C4, C5: 100n; R_1206_3216Metric_Pad1.30x1.75mm_HandSolder
C6, C7, C8: 10u; R_1206_3216Metric_Pad1.30x1.75mm_HandSolder
C13: 1u; R_1206_3216Metric_Pad1.30x1.75mm_HandSolder
F1: 0154003.DR; 0154Series_LTF
IC1: CH224K; SOP100P600X180-11N
J1: PJ-313D-B-SMT; PJ-313D-B-SMT_XKB
J2: GT-USB-7004; CONN12_B-7004_GSW
J3: DC-005-20A; DC00520A
J4: Conn_02x03_Top_Bottom; IDC-Header_2x03_P2.54mm_Vertical
J5: Conn_02x03_Counter_Clockwise; IDC-Header_2x03_P2.54mm_Vertical
J6: Conn_01x08_Pin; Molex_SL_171971-0008_1x08_P2.54mm_Vertical
J7: Conn_01x04; FanPinHeader_1x04_P2.54mm_Vertical
Jx1: Conn_01x04; FanPinHeader_1x04_P2.54mm_Vertical
L1: 10u; IND_NLCV32T_TDK
Q1, Q3: BSN20; SOT-23
Q2: IRF7416TRPBF; SO-8_IRF741_INF
R1: 100k; R_1206_3216Metric_Pad1.30x1.75mm_HandSolder
R2: 56k; R_1206_3216Metric_Pad1.30x1.75mm_HandSolder
R3, R4, R8, R9, R10, R15, R16, R17, R18, R19, R28: 1k; R_1206_3216Metric_Pad1.30x1.75mm_HandSolder
R5, R20: 1M; R_1206_3216Metric_Pad1.30x1.75mm_HandSolder
R6, R7, R21, R22, R23, R24, R25, R26, R27, R29: 10k; R_1206_3216Metric_Pad1.30x1.75mm_HandSolder
R11: 270k; R_1206_3216Metric_Pad1.30x1.75mm_HandSolder
R12: 51k; R_1206_3216Metric_Pad1.30x1.75mm_HandSolder
SW1, SW2, SW3, SW4: TS-1093C-A15; SW_TS-1093C-A15_YDI
U1: ATMEGA328P-AU; TQFP-32_7x7mm
U2: LM321; SOT-23-5
U3: TPS62175DQCR; DQC0010A
Y1: Crystal; Crystal_HC49-U_Vertical

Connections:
+5V: C3.2, C6.2, C7.2, C8.2, J4.5, J5.6, J6.3, J7.4, Jx1.2, L1.1, Q1.3 (D), R5.1, R11.1, R15.1, R21.1, R22.1, R23.1, R24.1, R25.1, R27.1, U1.4 (VCC), U1.6 (VCC), U1.18 (AVCC), U2.5 (V+), U3.8 (SLEEP), U3.10 (VOS)
+12V: J3.1, J4.3
GND: C1.1, C2.1, C3.1, C4.1, C5.1, C6.1, C7.1, C8.1, C13.2, IC1.2 (CFG1), IC1.3 (CFG2), IC1.11 (GND), J1.1A, J1.1B, J2.A1, J2.A12, J2.B1, J2.B12, J3.2, J3.3, J5.4, J6.1, J7.1, Jx1.1, Q3.2 (S), R1.1, R6.1, R7.1, R12.2, R20.2, R26.2, SW1.2, SW2.2, SW3.2, SW4.2, U1.3 (GND), U1.5 (GND), U1.21 (GND), U2.2 (V-), U3.1 (PGND), U3.6 (AGND), U3.11 (PAD)
unnamed: C13.1, IC1.1 (VDD), IC1.9 (CFG3), R28.1
unnamed: IC1.8 (VBUS), R29.2
unnamed: F1.1, J4.2
unnamed: J6.4, R16.2
unnamed: J6.5, R17.2
unnamed: J6.6, R18.2
unnamed: J6.7, R19.2
unnamed: J6.8, R15.2
unnamed: Q1.1 (G), R6.2, R8.2
unnamed: Q2.4 (G), R10.1
unnamed: Q3.1 (G), R7.2, R9.1
unnamed: R2.1, R3.2, U2.4
unnamed: C2.2, U1.7 (PB6), Y1.1
unnamed: C1.2, U1.8 (PB7), Y1.2
unnamed: C5.2, R4.1, U2.1 (+)
unnamed: R1.2, R2.2, U2.3 (-)
unnamed: R11.2, R12.1, U3.5 (FB)
unnamed: L1.2, U3.9 (SW)
VBUS: J2.A4, J2.A9, J2.B4, J2.B9, J4.1, R28.2, R29.1
VDC: F1.2, Q2.1 (S), Q2.2 (S), Q2.3 (S), Q3.3 (D), R10.2, U3.2 (VIN), U3.3 (EN)
analog_in: C4.2, R3.1, U1.11 (PD7)
bl: J6.2, Q1.2 (S)
bl_ctrl: R8.1, U1.12 (PB0)
cc1: IC1.6 (CC1), J2.A5
cc2: IC1.7 (CC2), J2.B5
cs: R19.1, U1.14 (PB2)
dc: R18.1, U1.13 (PB1)
dm: IC1.5 (DM), J2.A7, J2.B7
dp: IC1.4 (DP), J2.A6, J2.B6
miso: J5.1, U1.16 (PB4)
mosi: J5.5, R17.1
output_power: J1.2A, J1.2B, Q2.5 (D), Q2.6 (D), Q2.7 (D), Q2.8 (D)
poti: J7.2, R20.1, U1.10 (PD6)
reset: J5.3, R27.2, SW1.1, U1.29 (PC6)
s_ctrl: R9.2, U1.1 (PD3)
sb: J7.3, R21.2, U1.23 (PC0)
sck: J5.2, R16.1, U1.17 (PB5)
sens: J1.3A, J1.3B, R4.2, R5.2
sense_12v: J4.6, U1.2 (PD4)
sense_usb: J4.4, U1.9 (PD5)
standby: R25.2, R26.1, U1.19 (ADC6)
u1: R22.2, SW2.1, U1.26 (PC3)
u2: R23.2, SW3.1, U1.25 (PC2)
u3: R24.2, SW4.1, U1.24 (PC1)

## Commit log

2023-07-31 Creating Project with KiCad
    [ss_v2.kicad_pcb, ss_v2.kicad_sch]
2023-07-31 Delete KiCad/ss_v2 directory
    weg damit
    [ss_v2.kicad_pcb, ss_v2.kicad_sch]
2023-07-31 Generieren des Projektes
    [ss_v2.kicad_pcb, ss_v2.kicad_sch]
2023-07-31 Erstellen des Schaltplans der Version 1
    [ss_v2.kicad_sch]
2023-07-31 Standby pin hinzufeguegt
    [ss_v2.kicad_sch]
2023-07-31 korrektur der Fehlenden Footprints
    [ss_v2.kicad_sch]
2023-07-31 Anordnen der Bauteile
    [ss_v2.kicad_pcb]
2023-07-31 BOM hinzugefügt
    [ss_v2.csv]
2023-07-31 Erster Routing Versuch
    [ss_v2.kicad_pcb, ss_v2.kicad_sch]
2023-08-01 Autoroute-Bsp. hinzugefügt. Sollte sogar funktionieren.
    [ss_v2-autoroute.kicad_pcb]
2023-08-01 Autorouting verbessert
    [ss_v2-autoroute.kicad_pcb]
2023-08-01 Anpassen des Layouts
    [ss_v2-autoroute.kicad_pcb]
2023-08-01 Switch-Conn. angepasst.
    [ss_v2-autoroute.kicad_pcb]
2023-08-01 Fertigungsdateien erzeugt inkl. PDF des Schaltplans
    [ss_v2-autoroute-B_Cu.gbr, ss_v2-autoroute-B_Mask.gbr, ss_v2-autoroute-B_Paste.gbr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]
2023-08-02 Das ist ein Test, weil etwas nicht funktioniert.
    [ss_v2.1.kicad_pcb, ss_v2.1.kicad_sch]
2023-08-02 in ss_v2.1 wurde FUSB302 durch kleineren, einfacheren und günstigeren CH244 ersetzt.
    [ss_v2.1.kicad_sch]
2023-08-02 Schaltplan fertig. Einige Bauteil-Libs fehlen noch / werden nicht richtig erkannt. Das sollte behoben werden bevor das PCB abktualisiert werden kann...
    [ss_v2.1.kicad_sch]
2023-08-12 Versucht, FUSB zu ersetzen. Bin gescheitert, da KiCad genialerweise neue Bauteilnummern vergeben hat und man so jetzt das gessamte Layout neu machen müsste oder alle Nummern einzeln anpassen müsste. 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
    [ss_v2.1.kicad_pcb]
2023-08-12 ss_v2 mit neuem Chip umgesetzt. Sieht soweit gut aus, keine Probleme festgestellt. Bitte um Überprüfung.
    [ss_v2-autoroute.kicad_pcb, ss_v2-autoroute.kicad_sch, ss_v2.csv]
2023-08-19 GND an 328p gefixt
    [ss_v2-autoroute-B_Cu.gbr, ss_v2-autoroute-B_Mask.gbr, ss_v2-autoroute-B_Paste.gbr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]
